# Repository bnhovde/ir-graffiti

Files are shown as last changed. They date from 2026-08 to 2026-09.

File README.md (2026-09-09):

# IR Graffiti — spray can tracker

A handheld spray can emits infrared; a camera watches for it and paints where it
points.

**Status: it works.** A person picks up the can, points it at the TV, holds the
button and paints. All three of the original blockers are closed — manual
exposure, the LED's beam angle, and the Pi's power supply — and the Pi boots
into the wall unattended.

It works on the *interim* optics: a modified C910 behind a strip of VHS tape.
The mono global-shutter camera and the 850 nm bandpass filter are still in
transit, and they are what will make it robust rather than merely working.
Honest summary of where it stands:

| | |
|---|---|
| Can: 850 nm, 120°, one emitter | ✅ tracks reliably at painting distance |
| Power | ✅ 5 V/5 A negotiated, no throttling |
| Tracker | ✅ 30 fps, 4.6× margin over threshold |
| Wall app, calibration, painting | ✅ |
| Controls usable with the can | ✅ colour, mode, size |
| Boots into the wall by itself | ✅ user services, always ends at calibration |
| Rendering | ✅ **58.4 fps while painting** on a Pi 5 at 720p — the rewrite, against 24 for the original |
| Cooling | ✅ Active Cooler fitted: 53 °C, `throttled=0x0`, full 2.4 GHz (was 82 °C and throttling) |
| Latency | ⚠️ dominated by the C910's USB/MJPEG pipeline, ~60–130 ms, which only the CSI camera removes |
| Mono camera + bandpass filter | ⏳ in transit, untested |
| Usable cone angle | ⏳ never measured — `tools/pi/measure.py` is ready |
| Multiple simultaneous users | ❌ unsolved, unscoped |

## Try it

**▶ [bnhovde.github.io/ir-graffiti/test-wall.html](https://bnhovde.github.io/ir-graffiti/test-wall.html)**

Served from GitHub Pages off `main`, so it updates on every push.

- **Camera on the same machine:** camera panel → **IR can** → pick the camera →
  **Diagnostics** → **Calibrate 4 corners**.
- **Tracking on a Pi:** camera panel → **IR (Pi)** → **Connect** (it prefills
  `ws://<host>:8765`) → **Calibrate 4 corners**. The browser never sees pixels in
  this mode, only coordinates, so the diagnostics overlay has nothing to draw —
  use the tracker's own `/preview` instead.

Mouse and touch work without any of the hardware, if you just want to see the
wall itself.

To run it locally instead:

```bash
python3 -m http.server 8731
open http://localhost:8731/test-wall.html
```

Use `localhost`, not `file://` — `getUserMedia` only works in a secure context,
which `localhost` and HTTPS satisfy and a local file does not.

---

## Running it on the Pi

The Pi boots into the wall. Two systemd **user** services do it — user rather
than system because the browser needs the compositor, and `WAYLAND_DISPLAY`
only means anything inside the graphical session. The Pi autologins, so the
session exists at boot and these come up with it. No `linger`, no `sudo`.

```bash
git clone https://github.com/bnhovde/ir-graffiti ~/ir-graffiti
cd ~/ir-graffiti && ./tools/pi/install-pi.sh
systemctl --user restart irtracker irkiosk
```

| | |
|---|---|
| `irtracker` | the tracker: camera, detection, WebSocket on :8765, HTTP on :8000 |
| `irkiosk` | `start-kiosk.sh` — waits for the compositor, sets 720p, launches Chromium, connects it to the tracker, **starts calibration** |
| logs | `~/ir-graffiti/tracker.log`, `~/ir-graffiti/kiosk.log` |

**It always ends at the four corner targets.** The homography lives in the page,
so every restart genuinely needs it redone — and a wall that looks alive but
paints nothing is worse than one visibly asking to be calibrated.

720p is set on every boot because `wlr-randr` does not persist, and because the
resolution is the wall's frame rate: measured ~10 fps at 1440p, ~15 at 1080p and
34+ at 720p. The cost is pure fill rate.

### Why there are two walls

[`wall.html`](wall.html) is the one that boots. [`test-wall.html`](test-wall.html)
is the original and stays as a fallback — `WALL_URL` in `start-kiosk.sh` switches
between them.

The rewrite exists because the original's losses were structural, not tuning.
Measured on the Pi at 720p, while painting:

| | original | rewrite |
|---|---|---|
| painting | 24 fps | **58.4 fps** |
| idle | 60 fps | 60 fps |

Three canvases composited every frame became one that is never cleared; a
full-screen overlay cleared per frame to draw a cursor became a DOM element
moved by a transform; per-stamp gradients became cached bitmaps; and the
backing store is capped at 1×. Nothing animates on its own, so an idle wall
costs nothing and each theme's effects are paid for only while that theme is
selected.

### Operating it at the exhibition

The wall boots by itself and ends at the four corner targets. Everything else
is reachable **with the can alone** — rest it on a control and hold; a ring
fills, then the menu opens; move to highlight, release to pick.

| control | where | what |
|---|---|---|
| sizes · mode · colours | bottom left | five brush sizes, four modes, four colours |
| clear | top right | **hold ~1.8 s** — twice the menu dwell, because it wipes the wall |
| the frog | bottom right | **Calibrate · Reload · Friedolin · Sound** |

**Calibrate** is the one to know. The homography lives in the page, so any
reload needs it redone — and if the camera is nudged, the paint will land in
the wrong place until you recalibrate. It is in the frog menu precisely so
nobody needs a keyboard to fix it.

**Friedolin** places a large frog stencil: paint fills the silhouette and is
cut off outside it. Same item toggles it off.

**Sound** mutes the spray hiss and the choice persists. Worth knowing before
opening rather than after.

Modes are isolated by construction: Space builds its own animated layer on
entry and tears it down on exit, so nothing pays for it while another mode is
selected. Two cans paint at once, sharing a brush — the tracker matches spots
between frames, and when they cross the identities swap, which is invisible
while both use the same colour.

### Driving it with no mouse or keyboard

The exhibition Pi has neither, so [`tools/pi/kiosk.py`](tools/pi/kiosk.py) drives
the page over the Chrome DevTools Protocol:

```bash
python3 tools/pi/kiosk.py --status          # tracker state, calibration, lock
python3 tools/pi/kiosk.py --calibrate       # restart the 4-corner calibration
python3 tools/pi/kiosk.py --latency         # end-to-end latency, while painting
python3 tools/pi/kiosk.py 'app.clearCanvas()'
```

Also useful: `http://graffiti.local:8000/preview` is a live contrast-stretched
camera view for aiming (a correctly exposed IR frame looks black to a human),
and `/debug-pointer.html` shows just the tracked dot with a latency readout — no
canvas, no painting, so it is the floor the wall can be compared against.

---

## The can

Six printed parts, modelled parametrically in [`canv2.scad`](canv2.scad). All
print without supports. About 160 mm tall, 60 mm diameter.

| Part | Key dimensions | Notes |
|---|---|---|
| `body` | ⌀60 × 145 | 2 mm wall, 15 mm shoulder cone, 18 mm neck with a snap bead. Prints upright, open end down. |
| `cap_body` | ⌀36 × 22.6 | Internal shelf carries the button plate so press force goes into the can, not the plate. Nozzle spout ⌀18, standing 4 mm proud, with the LED cast in its face. |
| `cap_top` | ⌀36, 4.1 plug | Snaps on via a split collet. Pry slot at the seam opposite the nozzle. |
| `button_disc` | ⌀31.7 × 2.5 | Holds the switch. Pin holes on a 12.5 × 4.5 grid. |
| `bottom_cap` | ⌀60 × 65.5 | Snap-in base with a slide-in cradle for the battery holder. Two pry slots at 0° and 180°. |
| `nozzle_cap` | ⌀14.9 × 0.8 | The bezel. Presses into the nozzle rebate and clamps the LED into its cast. Prints flat. |

Set `part=` to export one part, or leave it at `"all"` for the layout view.
Exported STLs are in [`stl/`](stl). Everything derives from the parameter block
at the top; the numbers worth knowing are `fit` (0.30, raise it if parts bind),
`hold_w` (36.20, cut for the CM battery holder), and the LED block below.

### How the emitter mounts

The LED **drops into a cast in the front of the nozzle** and a thin bezel presses
on over it, leaving the body and dome outside. Same pattern as `button_disc`
sitting on its shelf under `cap_top`: a part in a recess, closed by a cover.

Three steps in from the nozzle face:

```
0.0 → 0.8    ⌀15.0 rebate      the bezel sits here
0.8 → 2.0    ⌀8.4 + tab slot   the cast: the LED's own silhouette
2.0 → 2.4    ⌀6.6 relief       so the body seats on its rim, not the slug
```

Two ⌀2.5 wire holes run from the cast back into the wiring chamber. **Solder the
leads on, feed them through, drop the LED in, press the bezel on.**

| Parameter | Value | Why |
|---|---|---|
| `pled_cover_t` | 0.8 | Bezel thickness — all that sits beside the dome, so as thin as the printer holds |
| `pled_cover_fit` | 0.10 | Bezel to rebate. Tight on purpose: a press fit, not the sliding `fit` used elsewhere. A drop of glue behind it if you want it permanent |
| `pled_tab_span` | 14.5 | Untrimmed. Sizes the cast and hence the spout |
| `pled_tab_stag` | 1.5 | The tabs are **staggered, not opposite**. Slot is `tab_w + this`, centred, so the part goes in either way up. Read off a drawing — measure yours |
| `pled_body_h` | 2.4 | Tab plane to body top. Sets how far the body protrudes; more just means more sticks out |

The body ends up 1.2 mm proud and the dome tip 3.8 mm clear of the face, with
nothing in front of the dome — the full 120°.

> [!NOTE]
> **An earlier version loaded the LED from inside the cap**, sliding it forward
> down the bore onto a shoulder, with the tabs as retention. It verified fine and
> was almost impossible to build: you were threading a part with leads already
> soldered to it down a channel you could not see into. Front-loading also means
> the LED never enters the wiring chamber, so the chamber — and the whole cap —
> goes back to its original height, 24.6 mm rather than 28.3.

> [!TIP]
> The ⌀15 rebate ceiling is the largest bridge in the part, about 10 mm across
> but only 0.8 mm deep. If it sags enough that the bezel will not seat flush,
> scrape it or raise `pled_cover_fit`.

### Electronics

| Item | Spec | Notes |
|---|---|---|
| IR LED *(incoming)* | 1 × 8 mm star emitter, **850 nm, 120°**, 3 W rated | Body ⌀8.0 (7.2 across the flats), dome ⌀6.0 × 2.6 tall, thermal slug ⌀6.2, tabs 1.5 × 1.05 spanning 14.5, marked IR+ / IR−. Vf 1.4–1.7 V at 500 mA — **single die, so it runs on 3 V**. Some parts sold as "3 W" are three dies in series at 4.5–5 V and will not light at all here; check before wiring. |
| Resistor | **22 Ω**, 0.25 W | One, in series. Gives ~70 mA — 4× the old drive with plenty of margin. 15 Ω takes it to ~110 mA if you want more range. **Do not drive it at the rated 500 mA:** that is 0.75 W with no heatsink, in a plastic cap, and 2×AAA sag badly at that current. At 70 mA the LED dissipates ~0.1 W and heat is a non-issue. |
| Switch | 12 × 12 mm tactile | 4-leg. See wiring warning below. |
| Battery | 2 × AAA, 3.0 V | Printed holder `AAA_holder_di_CM.stl` from [`AAA_holder.3mf`](AAA_holder.3mf), 36.2 × 56.5 × 12 mm, slides into the base cradle. |
| Camera | Logitech C910, or OV9281 *(incoming)* | See below. |
| Host | Raspberry Pi 5 | Runs the tracker and the browser. **Needs the 27 W supply** — see findings. |

**Superseded:** 2 × ⌀3 mm 940 nm ([Fibel](https://www.fibel.no/product/940nm-sender-og-mottaker-ir-leder/)) at 17 mA through 100 Ω each. Kept here only so the old wiring is recognisable. 940 nm is the worst case for a silicon sensor and the ~±20° beam is what the whole rebuild is about.

---

## Wiring

One branch, one LED. Pressing the button lights it, and that *is* the trigger
signal — the tracker treats "LED visible" as pen-down, so the button needs no
telemetry of its own.

```mermaid
graph LR
    BAT["Battery +<br/>2 x AAA, 3.0 V"]
    SW["Tactile switch<br/>12 x 12 mm<br/>diagonal legs"]
    R["22 ohm<br/>0.25 W"]
    D["IR LED<br/>850 nm, 120 deg<br/>~70 mA"]
    GND["Battery -"]

    BAT -->|red| SW
    SW --> R
    R -->|to IR+| D
    D -->|black, from IR−| GND
```

Polarity is printed on the part: **IR+** and **IR−** next to their tabs, so there
is no long-leg/short-leg guessing any more.

> [!TIP]
> **Solder the leads before fitting the LED**, then feed them back through the
> wire holes. The tabs are bonded to the thermal slug and sink heat fast, so use
> a big tip and be quick.

> [!WARNING]
> **Which switch legs.** On a 4-leg tactile switch the two legs **12.5 mm apart,
> straight across the body,** are one terminal. The two close together on the
> same side are *opposite* terminals — bridging those shorts the switch
> permanently on. Wire two diagonally opposite legs and clip the other two;
> diagonals are always one from each terminal, which is why that's the standard
> trick.

---

## The camera

No longer the weak link — moving the tracker onto a Pi fixed the part that
mattered. The C910 on a Pi is a genuinely usable camera.

### Working today: modified C910 on the Pi

| | |
|---|---|
| **Body** | Logitech C910. USB 2.0 UVC, colour sensor, autofocus, ~78° diagonal field. Roughly 70° horizontal in 16:9, so lateral coverage is about 1.4 × distance. |
| **IR-cut filter** | **Removed.** Physically taken out of the lens stack so the sensor can see near-IR at all. This shifts the focal plane — IR focuses differently from visible — so autofocus sits slightly wrong and is locked in software. |
| **IR-pass filter** | **A strip of VHS tape over the front glass.** Improvised and the weakest optical element in the chain. Worth 2–8× to replace with real filter glass. |
| **Exposure / gain** | **Manual, and it works.** `auto_exposure=1`, `exposure_time_absolute=60` (6 ms), `gain=128`, verified by readback. On macOS every one of these returned min 0 / max 0. See the settings finding below — 2 ms / gain 8 was wrong for this optical chain and capped the range. |
| **Format** | **MJPEG, forced.** V4L2 hands back uncompressed YUYV by default and 720p of that exceeds USB 2.0 bandwidth, so the camera silently settles at 10 fps. Asking for MJPEG first gets 30. |
| **Enumeration** | USB VID `0x046d`, PID `0x0821`. `/dev/video0` on the Pi. |

### Incoming: OV9281 + 850 nm bandpass

Mono global shutter, no Bayer filter (~3× the sensitivity of the colour C910),
and a proper filter instead of tape. Together worth roughly 6–24× signal, which
buys **range**, not angle — see the finding on beam width below.

> [!CAUTION]
> **Do not fit the 850 nm bandpass with the old 940 nm LEDs.** A narrow 850 nm
> passband rejects 940 nm by three or four orders of magnitude. You would see
> nothing at all, and it looks exactly like a dead camera. Swap the LED and the
> filter together.

One risk to watch: narrow bandpass filters blue-shift with incidence angle, so
transmission can fall at the edges of a wide field of view. If the screen corners
go dark, that is why — a wider filter or a 780 nm longpass is the fix.

---

## Two camera geometries, one of them dead

The project was originally drafted around bouncing IR off the wall and watching
the reflection from the back of the room. That does not work and cannot be made
to work at this power level. The camera now sits **at the wall, looking back at
the user**, so it sees the LED directly.

| | Bounce off the wall | Direct view |
|---|---|---|
| Camera position | Back of the room | At the wall, facing the user |
| Path | LED → wall → scatter → camera | LED → camera |
| Result | **No reading at all** | **Verified to 3 m** |
| Shortfall | ~1000× too dim | — |

A diffuse wall scatters the LED's output over a hemisphere and the camera then
collects a vanishing fraction of it. Closing that gap would need several watts
per steradian — an illuminator array, not two LEDs on a pair of AAAs. Correctly
abandoned; **do not revisit.**

The cost of the direct path is that the camera only covers about 1.4 × its
distance from you, so a 2 m wall means standing ~1.5 m back, and accuracy
depends on a homography calibrated at roughly that distance.

---

## Findings

Measured, not assumed.

### ✅ Direct-view tracking reaches 3 m

With the VHS filter fitted, the old 3 mm LEDs at 17 mA and no other
optimisation, the camera tracked the LED reliably to about 3 m **when pointed at
the lens**. That last clause is the whole problem — see the beam-angle finding —
but as a range figure it is the baseline everything else is measured against.

### ❌ Bouncing off the wall is ~1000× short

No reading whatsoever off a wall, at any distance, while the direct path was
comfortable. See above.

### ❌ macOS will not expose UVC camera controls — ✅ Linux will

`uvcc` enumerates the C910 correctly on macOS but every control transfer hangs,
and `uvcc ranges` returns min 0 / max 0 for every control: the system's own UVC
driver owns the control interface and will not release it. AVFoundation ignores
exposure and gain too.

**On the Pi the same camera reports `exposure_time_absolute` min 3 max 2047 and
honours it.** This was the project's oldest blocker and the fix was to change
host, not camera. At 2 ms with gain 8 the room reads luma 5 — near-black — which
is exactly the intent: ambient accumulates with exposure time while the LED
saturates almost instantly.

### ✅ Settings, measured rather than assumed

The working configuration for the modified C910 behind VHS tape:

```
exposure  6000 us (6 ms)      gain  128
min_luma  25                  floor 12
```

Exposure sweep, LED at painting distance, gain 128:

| exposure | sig | thr | result |
|---|---|---|---|
| 2 ms | 16.9 | 12.0 | no detection |
| **6 ms** | **55.4** | 12.0 | **LOCKED** — 4.6× margin, threshold still on its floor |
| 10 ms | 78.6 | 17.2 | locked, but margin flat |
| 20 ms | 123.6 | 29.7 | locked, ambient now paying for it |

Past 6 ms the adaptive threshold rises with the signal, so the margin stops
improving and only the room light grows. Short exposure is still what rejects
ambient — 6 ms is short — but **2 ms was dogma, not a measurement**, and it was
carried for most of this project on the strength of the sentence above it.

Two settings were quietly limiting range for weeks:

- **`min_luma` is an ABSOLUTE pixel threshold**, so its meaning moves with gain
  and exposure. It was set to 55 once, to kill false positives, and from then on
  a blob had to exceed 55/255 no matter how the camera was configured. It should
  sit just above sensor noise and let the adaptive threshold and the persistence
  gating filter properly.
- **`--gain` meant different things on the two backends** — an analogue
  multiplier on picamera2, a 0–255 register on a UVC webcam — and shared one
  default of 8.0. Sensible for picamera; very nearly nothing on a webcam. The
  C910 ran at 8/255 for this entire project. Each backend now carries its own
  default.

Symptom to recognise: detection that works close up and **vanishes as a cliff**
rather than fading. That is an absolute gate, not a weak emitter. Hours went into
checking the LED, the batteries, the solder joints and the camera aim, all of
which were fine, because a working measurement of `peak 66` against a gate of
`55` was read as "working" rather than "20% from failing".

### ⚠️ Current blocker: the LED's beam, not the signal

The old 3 mm LEDs held lock only within roughly ±20°, so the can had to be aimed
at the camera rather than painted with.

The decisive measurement: **the same ±20° cone appeared on a Mac at ~16 ms auto
exposure and on a Pi at 2 ms manual.** Two sensitivity regimes an order of
magnitude apart, identical usable angle. A signal problem cannot survive that, so
the limit is the beam.

The arithmetic agrees. Falloff is roughly cos²²θ, so sensitivity barely moves the
angle — 6–24× more signal widens the usable half-angle from about 20° to 23–30°.
The same 6–24× spent on range buys 2.4–5×, because that goes as the square root.

**The fix is a wider emitter, not a brighter one.** A 120° part changes the
exponent rather than the multiplier. At 45° off-axis the old LED is at ~0.0005 of
peak and a 120° one is at ~0.7.

### ✅ The C910's first open returns a dead stream

Worth knowing because it wastes an evening. The camera enumerates, streams at a
valid 30 fps, and every pixel of every frame is the same value. It looks exactly
like a blocked lens. The kernel log shows the real cause — the first probe fails
with `-5` and the device re-enumerates — and Photo Booth shows the same thing:
you have to select the camera, select another, and select it back.

`tracker.py` now validates at startup while still on auto exposure, where a live
sensor always shows read noise, and reopens on a single-valued frame. Checking
after the switch to 2 ms would not work: a dark room at 2 ms is legitimately
almost flat.

### ❌ A 15 W supply will not run a Pi 5 with this camera

Three hard crashes, then a fourth. The firmware says why:

```
max_current              = 3000     5 V x 3 A = 15 W
usb_max_current_enable   = 0        USB peripherals capped at 600 mA total
usbpd_power_data_objects = 0 0 0    no PD profile offered at all
```

A MacBook charger does not advertise a 5 V/5 A profile, so the Pi falls back to
5 V/3 A and clamps **all** USB peripherals to 600 mA combined. The C910 alone can
draw 500 mA of that. Under load the board browns out and resets.

Confirmed by watching `vcgencmd get_throttled` flip to `0x50000` (under-voltage
and throttling both latched) within 20 seconds of the camera streaming, **with no
browser running at all**. Dropping the display to 1080p helped and was not
enough.

Use the official 27 W supply. Do **not** set `usb_max_current_enable=1`, the
common forum advice — it lifts the safety cap without adding a single watt, and
converts a clean refusal into an unpredictable brownout. A powered hub for the
camera is a legitimate workaround; it takes 500 mA off the Pi's budget entirely.

---

## Open questions

**~~Projector lamp~~ — settled.** The display is an **LED TV**, which emits no
meaningful near-IR, so the projector-lamp question is moot and a modest filter
suffices. Recorded because it drove several earlier decisions.

**Multi-user — unsolved, and in scope.** Identical IR LEDs are indistinguishable
and the tracker finds exactly one blob. Two cans in frame gives two spots with no
way to tell which is which. Telling them apart means blink-coding an ID into each
can, which means a microcontroller per can. None of the incoming hardware
addresses this. It is genuine new engineering and remains unscoped.

**Calibration in anger.** The 4-corner homography has never been completed on the
Pi — the board browned out first. Nothing paints without it: `processFrame()`
returns null with no homography, by design.

**Room lighting** — less of a risk than it sounds. Behind a proper filter, LED
and fluorescent lighting are nearly invisible; they emit almost no near-IR.
Brightness is not the variable, spectrum is. Halogen, incandescent and daylight
are the ones that hurt.

---

## Next step

Assemble the new emitter and **measure the usable cone before changing anything
else**. Hold the can at a fixed distance and rotate it until lock drops. If that
is not at least ±45°, the beam-angle reasoning above is wrong and the right move
is to re-measure, not to pile on more changes.

Then, in order: 27 W supply, new camera and filter together, 4-corner
calibration, and only then multi-user.

> [!NOTE]
> **A correction worth keeping.** An earlier version of this file recommended
> TSAL6100/6200-class emitters, chosen for intensity. Those are narrow-beam parts
> — roughly ±10° and ±17° — and that advice was backwards. Now that beam angle is
> known to be the binding constraint and there is 30× of sensitivity in reserve
> (the tracker locks at gain 8 of 255 and 2 ms of a possible 205), the selection
> criterion is the **widest** half-angle available at 850 nm, not the brightest.

**Rear projection is also dead** as a suggestion: the display is an LED TV.

None of the can hardware is wasted by any of this. Enclosure, button, battery
holder and switch wiring all carry over; only the LED and its resistor change.

Sourcing from Norway: Digi-Key, Mouser and Elfa Distrelec all ship and are
VOEC-registered (VAT at checkout, no customs handling fee). Arducam direct, The
Pi Hut, or BerryBase for the camera. AliExpress is fine for the filter.

---

## Repository layout

| Path | What |
|---|---|
| [`canv2.scad`](canv2.scad) | Parametric model, all five parts |
| [`stl/`](stl) | Exported STLs |
| [`AAA_holder.3mf`](AAA_holder.3mf) | Third-party battery holder. Use the `AAA_holder_di_CM.stl` variant — the cradle is cut for its 36.2 mm width |
| [`test-wall.html`](test-wall.html) | The wall app — [live](https://bnhovde.github.io/ir-graffiti/test-wall.html). Has an **IR can** camera mode: pure-JS blob tracking, rolling background, 4-corner homography calibration, and a diagnostics overlay showing the brightest pixel with no thresholding applied. `app.irTracker` is exposed on the console for tuning |
| [`tools/pi/tracker.py`](tools/pi/tracker.py) | **The Pi tracker.** Captures, finds the blob, broadcasts normalised coordinates over a WebSocket on :8765, and optionally serves the repo over HTTP. `--source picamera\|webcam\|synthetic`. Also serves a live contrast-stretched camera preview at `/preview` for aiming — necessary because a correctly exposed IR frame looks black to a human |
| [`tools/pi/kiosk.py`](tools/pi/kiosk.py) | Drives the wall app in a kiosk browser over the Chrome DevTools Protocol, for a Pi with no mouse. `--connect`, `--calibrate`, `--status`. Also takes a screen wake lock |
| [`tools/irtest.py`](tools/irtest.py) | Standalone Python tuner for the same pipeline, with a live HUD. Needs `opencv-python` |
| [`tools/ircam-setup.sh`](tools/ircam-setup.sh) | Attempts manual camera control via `uvcc`. **Known not to work on macOS**, and superseded on Linux by `tracker.py`, which sets the same controls through `v4l2-ctl` and reads them back |
| [`canv1.scad`](canv1.scad) | Superseded first draft, kept for reference |

### Reading the diagnostics overlay

In order — each step is only worth doing if the previous one passed.

0. **In Pi mode, none of this applies** — the browser receives coordinates, not
   pixels. Use the tracker's `/preview` page and its `--stats` line instead.
1. **`camera`** — if that's not the modified camera, nothing else matters.
2. **Red cross** — the brightest pixel in the frame, no thresholds at all. Press
   the button. If red doesn't jump to the LED, the problem is upstream of all
   this software.
3. **`maxLuma` / `maxSig`** with the LED on vs off. That difference is the entire
   signal budget.
4. Only if red lands correctly but no green circle appears is the sensitivity
   slider (`k`) the thing to touch.

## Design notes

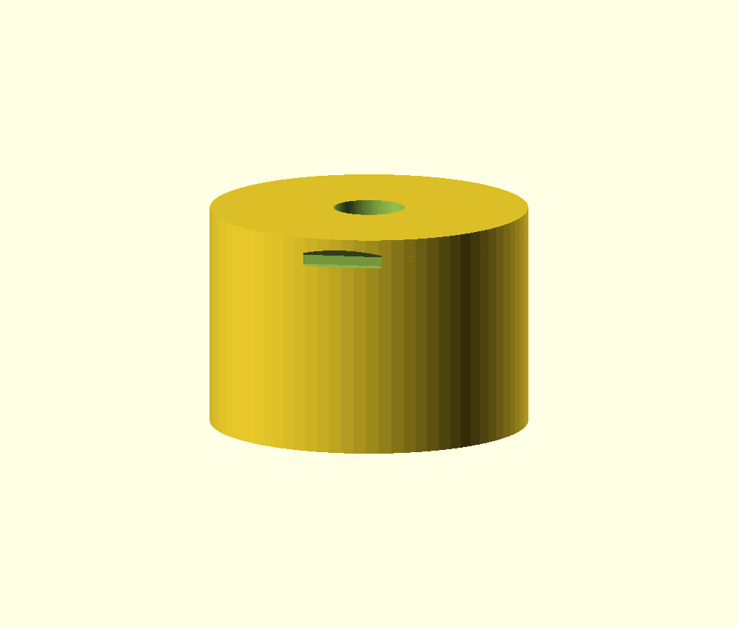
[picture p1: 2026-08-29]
preview_pry.png

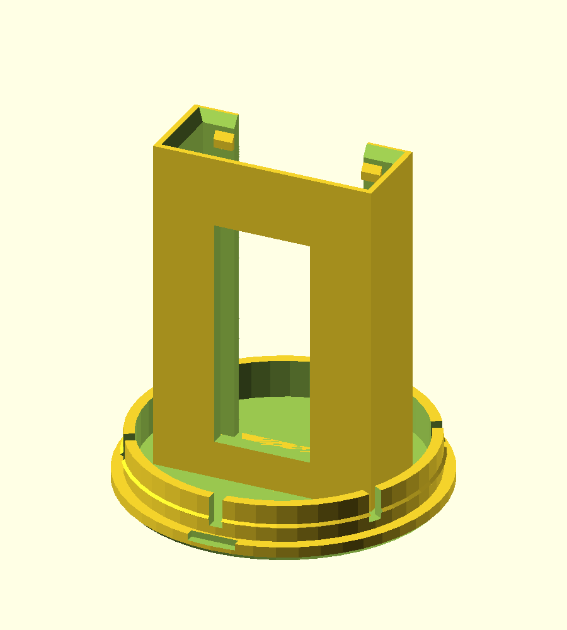
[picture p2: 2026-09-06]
preview_cradle.png

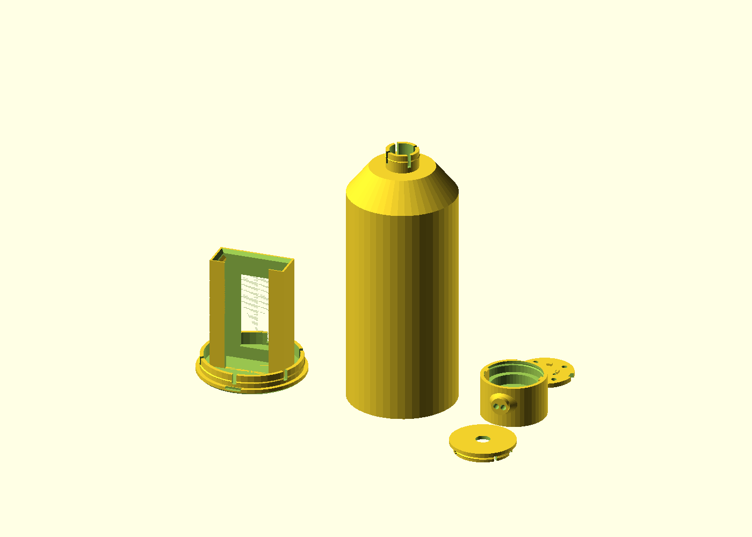
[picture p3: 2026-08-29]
preview.png

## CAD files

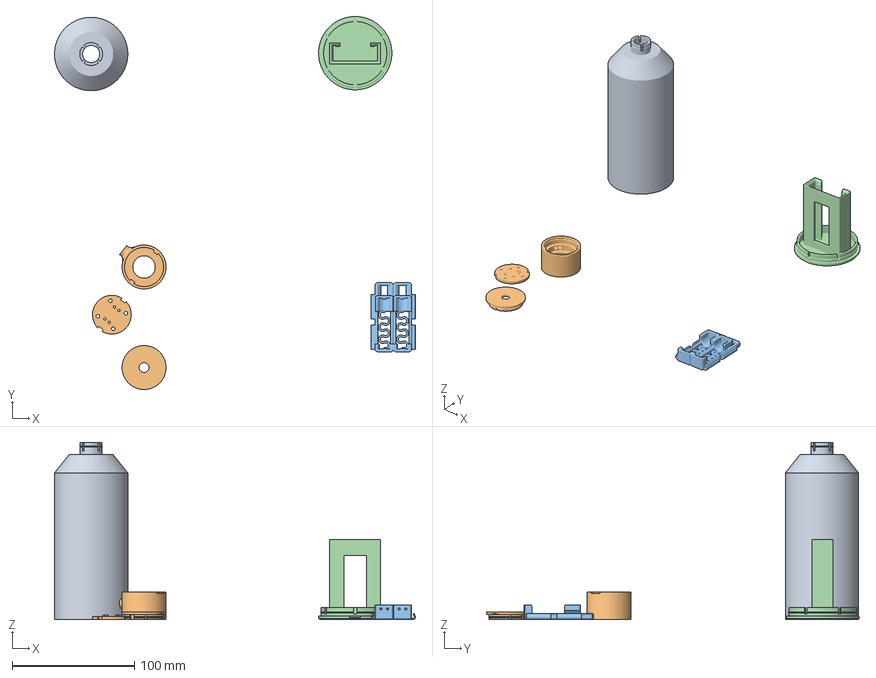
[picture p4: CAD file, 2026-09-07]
Full project September 6.3mf
295.3 x 305.1 x 145.0 mm
body.stl
button_disc
AAA_holder_di_CM.stl
bottom_cap.stl

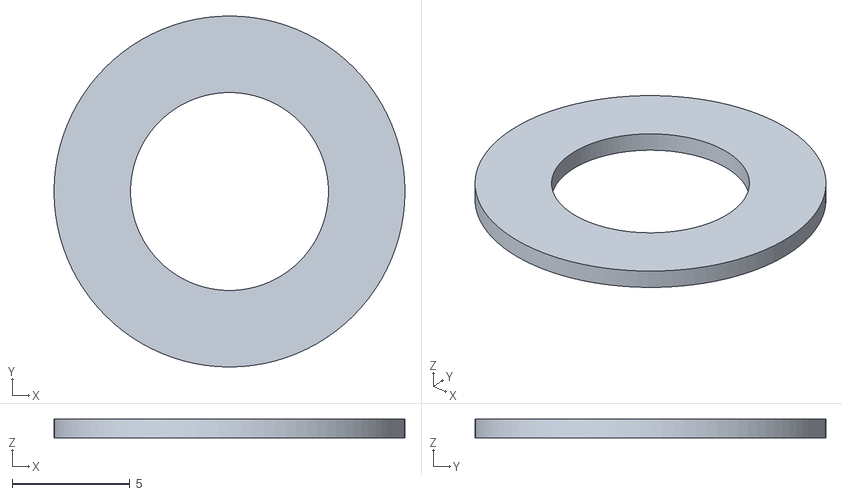
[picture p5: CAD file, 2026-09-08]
stl/nozzle_cap.stl
14.9 x 14.9 x 0.8

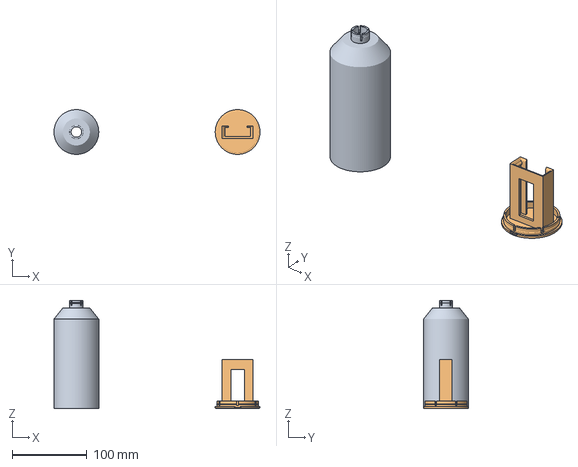
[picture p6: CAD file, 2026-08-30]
project.3mf
276.0 x 60.0 x 145.0 mm
body.stl
bottom_cap.stl

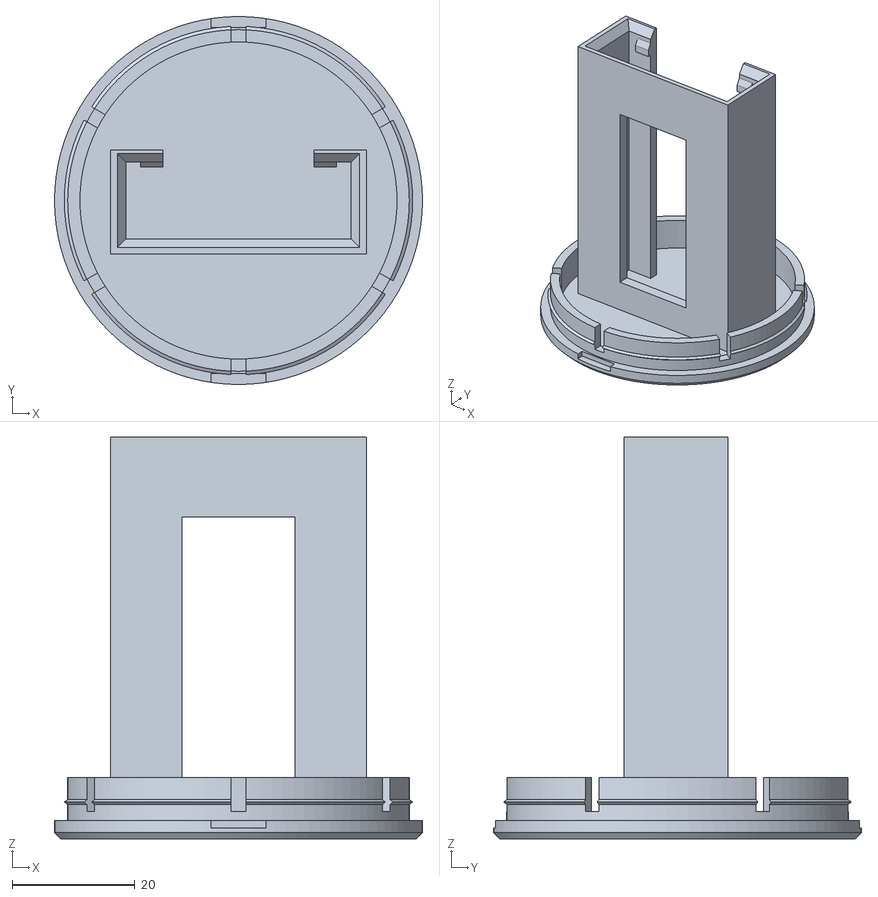
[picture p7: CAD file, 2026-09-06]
stl/bottom_cap.stl
60.0 x 60.0 x 65.5

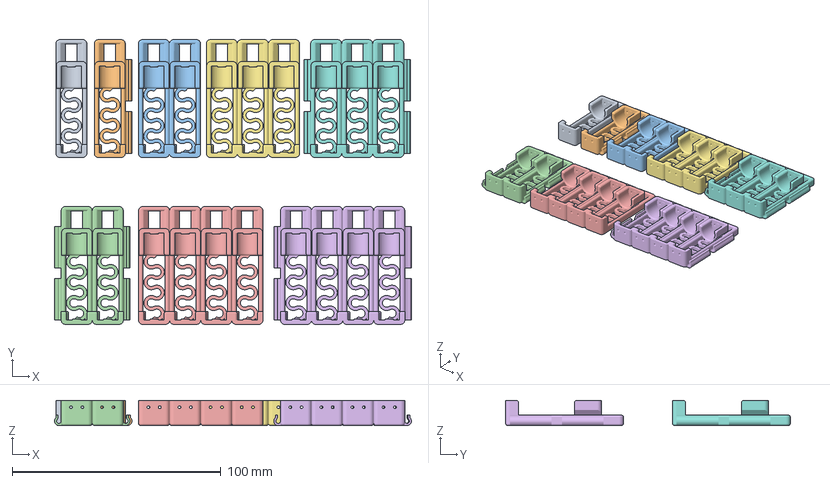
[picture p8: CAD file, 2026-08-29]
AAA_holder.3mf
171.1 x 136.5 x 12.0 mm
AAA_holder.stl
AAA_holder_CM.stl
AAA_holder_di.stl
AAA_holder_di_CM.stl
AAA_holder_tetra.stl
AAA_holder_tetra_CM.stl
AAA_holder_tri.stl
AAA_holder_tri_CM.stl

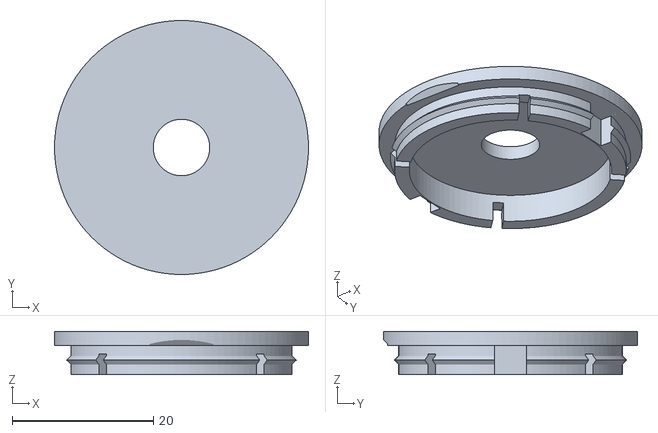
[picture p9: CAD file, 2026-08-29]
stl/cap_top.stl
36.0 x 36.0 x 6.10

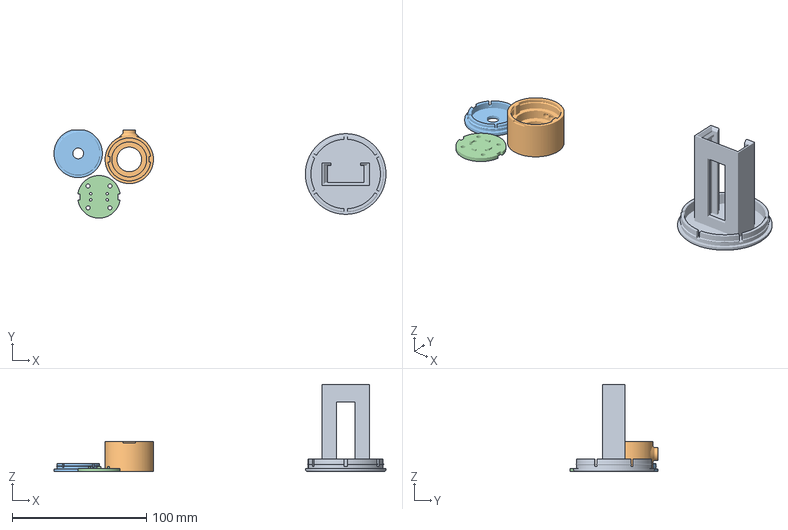
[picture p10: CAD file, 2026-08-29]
stl/cap_body.3mf
247.0 x 65.7 x 65.0 mm
bottom_cap.stl
cap_body.stl
cap_top.stl
button_disc.stl

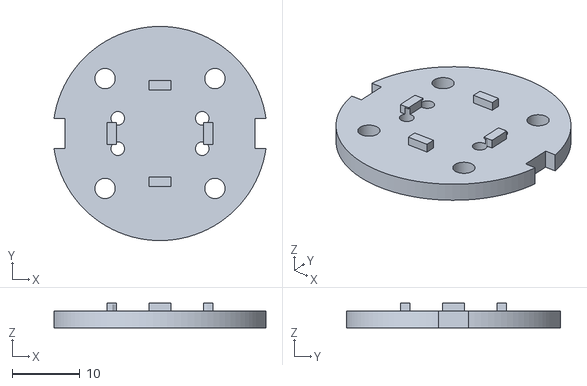
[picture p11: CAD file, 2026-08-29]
stl/button_disc.stl
31.4 x 31.7 x 3.70

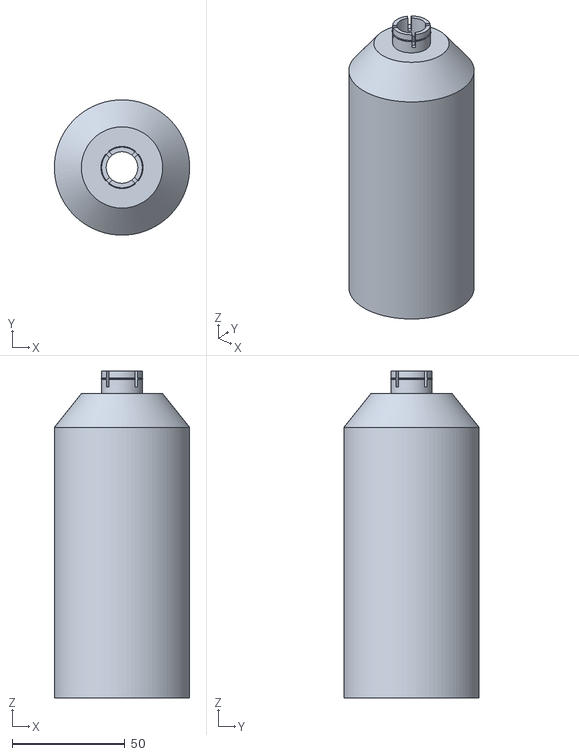
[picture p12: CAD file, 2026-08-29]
stl/body.stl
60.0 x 60.0 x 145.0

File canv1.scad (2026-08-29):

/*
  Digital Graffiti Spray Can Enclosure
  Modular Design with Through-Cut Alignment Grooves & External Battery Slot
*/

can_diameter = 60;
can_height = 120;
cap_height = 25;
wall_thickness = 2;

cap_outer_d = 28;
cap_inner_d = cap_outer_d - (wall_thickness * 2); 

led_hole_diam = 3.2; 

// Tactile Switch Mount Dimensions
switch_width = 12.4;     
switch_base_h = 3.5;     
switch_actuator_d = 8.0; 
pin_pitch_x = 12.5; 
pin_pitch_y = 4.5;  
pin_hole_diam = 2.0;

// External Battery Holder Dimensions (Adjust these to match your AAA_holder.3mf)
holder_w = 26.0;  // Width of external holder
holder_d = 13.0;  // Depth/thickness of external holder
holder_h = 48.0;  // Height/length of external holder
holder_tol = 0.3; // Clearance for sliding fit

$fn = 100;

// --- 1. Main Body Module ---
module main_body() {
    difference() {
        union() {
            cylinder(h=can_height, d=can_diameter);
            translate([0, 0, can_height])
                cylinder(h=15, d1=can_diameter, d2=cap_outer_d);
            translate([0, 0, can_height + 15])
                cylinder(h=8, d=cap_inner_d - 0.4); 
        }

        translate([0, 0, -wall_thickness])
        union() {
            cylinder(h=can_height, d=can_diameter - (wall_thickness*2));
            translate([0, 0, can_height])
                cylinder(h=15, d1=can_diameter - (wall_thickness*2), d2=cap_inner_d - 0.4 - (wall_thickness*2));
            translate([0, 0, can_height + 15])
                cylinder(h=12, d=cap_inner_d - 0.4 - (wall_thickness*2));
        }
    }
}

// --- 2. Detachable Top Cap Module ---
module top_cap() {
    union() {
        difference() {
            cylinder(h=cap_height, d=cap_outer_d);

            translate([0, 0, -0.1])
                cylinder(h=cap_height - wall_thickness - switch_base_h + 0.1, d=cap_inner_d);

            translate([0, 0, cap_height - 5])
                cylinder(h=10, d=switch_actuator_d);

            translate([-(switch_width/2), -(switch_width/2), cap_height - wall_thickness - switch_base_h])
                cube([switch_width, switch_width, switch_base_h + 0.1]);

            translate([-10, -6, cap_height/2])
                rotate([0, 90, 0])
                cylinder(h=30, d=led_hole_diam);

            translate([-10, 6, cap_height/2])
                rotate([0, 90, 0])
                cylinder(h=30, d=led_hole_diam);
        }
        
        // Alignment Rails
        translate([(cap_inner_d/2) - 1, -1, 0])
            cube([1, 2, cap_height - wall_thickness - switch_base_h]);
            
        translate([-(cap_inner_d/2), -1, 0])
            cube([1, 2, cap_height - wall_thickness - switch_base_h]);
    }
}

// --- 3. Bottom Lid & External Battery Holder Clip ---
module bottom_cap() {
    union() {
        // Base plate
        cylinder(h=wall_thickness, d=can_diameter);
        
        // Insert lip
        translate([0, 0, wall_thickness])
            cylinder(h=5, d=can_diameter - (wall_thickness*2) - 0.4);
            
        // Slot/Bracket for external battery holder
        translate([0, 0, wall_thickness])
        union() {
            difference() {
                // Outer retaining sleeve
                translate([0, 0, holder_h/2])
                    cube([holder_w + 4, holder_d + 4, holder_h], center=true);

                // Inner slot cavity
                translate([0, 0, holder_h/2 + 1]) 
                    cube([holder_w + (holder_tol*2), holder_d + (holder_tol*2), holder_h + 2], center=true);

                // Front cutout to allow flex (creates the snap "clip" action)
                translate([0, holder_d/2, holder_h/2 + 2])
                    cube([holder_w - 8, 4, holder_h + 2], center=true);
                    
                // Wire routing holes at the base of the slot
                translate([-6, 0, -1]) cylinder(h=5, d=3.5);
                translate([6, 0, -1]) cylinder(h=5, d=3.5);
            }
            
            // Snap-fit retention bumps (detents) inside the top of the sleeve
            translate([(holder_w/2) + holder_tol - 0.2, 0, holder_h - 4])
                sphere(d=1.5);
            translate([-((holder_w/2) + holder_tol - 0.2), 0, holder_h - 4])
                sphere(d=1.5);
        }
    }
}

// --- 4. Button Locking Disc Module ---
module button_locking_disc() {
    difference() {
        cylinder(h=2, d=cap_inner_d - 0.2);

        // 4 Pin Holes
        translate([pin_pitch_x/2, pin_pitch_y/2, -1]) cylinder(h=4, d=pin_hole_diam);
        translate([pin_pitch_x/2, -pin_pitch_y/2, -1]) cylinder(h=4, d=pin_hole_diam);
        translate([-pin_pitch_x/2, pin_pitch_y/2, -1]) cylinder(h=4, d=pin_hole_diam);
        translate([-pin_pitch_x/2, -pin_pitch_y/2, -1]) cylinder(h=4, d=pin_hole_diam);
            
        // Through-Cut Alignment Grooves
        translate([(cap_inner_d/2) - 0.5, 0, 1])
            cube([3, 2.4, 4], center=true);
            
        translate([-(cap_inner_d/2) + 0.5, 0, 1])
            cube([3, 2.4, 4], center=true);
    }
}

// --- 5. Render Layout ---
main_body();

translate([can_diameter + 15, 0, 0])
    bottom_cap();

translate([-can_diameter/2 - 15, 0, 0])
    top_cap();

translate([-can_diameter/2 - 15, cap_outer_d + 15, 0])
    button_locking_disc();

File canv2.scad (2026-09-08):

/* ============================================================================
   Digital Graffiti Spray Can Enclosure  --  v2
   ----------------------------------------------------------------------------
   Changes vs v1:

     1) CAP is now three parts. The button plate can no longer be pushed down:
        it drops onto a solid internal shelf in cap_body and is clamped there
        by the plug on cap_top, which snaps into cap_body. Finger force goes
        disc -> shelf -> can, not into the disc's edges.

     2) BATTERY BOX is gone. The bottom cap now carries a slide-in cradle for
        the printed AAA_holder_di_CM.stl (dual AAA with cable management,
        36.2 x 56.5 x 12 mm) out of AAA_holder.3mf. Pull the bottom cap off and
        the loaded holder comes with it, open face outward, batteries fully
        accessible.

   PRINT ORIENTATION (no supports anywhere)
     body        : as modelled, upright, open end down.
     cap_body    : as modelled, rim up. The nozzle's 45 deg collar keeps it
                   support-free; only ~3 mm under the spout tip bridges.
     cap_top     : UPSIDE DOWN - roof flat on the bed, plug pointing up.
     button_disc : flat.
     bottom_cap  : as modelled, plate on the bed.

   LED AIM
     The LEDs fire radially, out a nozzle boss on the side of the cap - the way
     a real spray can sprays. Hold the can upright with your finger on the
     button and the nozzle toward the wall.

     NOTE, 30 Aug 2026: the original plan was for the IR to bounce off the wall
     and be seen by a camera at the back of the room. That was measured and is
     dead - roughly 1000x too dim. The camera now sits AT the wall looking back
     at the user, so the nozzle points straight at it and the camera sees the
     LEDs directly, so the radial nozzle is still correct; only the camera
     moved.

     NOTE, 8 Sep 2026: the pair of 3 mm 940 nm indicators is gone, replaced by
     a single 8 mm 3 W 850 nm emitter with a 120 degree beam. Measured on both
     a Mac at 16 ms auto exposure and a Pi at 2 ms manual, the old LEDs held
     lock only within about +/-20 degrees - the same cone in two sensitivity
     regimes an order of magnitude apart, which says the limit was the beam,
     not the signal. The "front" and "side" LED modes went with them.

   ASSEMBLY
     To open either end: flat screwdriver into the slot at the seam, twist. Up
     top there is one, opposite the nozzle; at the bottom there are two,
     opposite each other, so you can walk the cap off level. In both cases the
     blade bears on the fixed part one way and the removable part the other.

     Push each LED down its nozzle channel from inside the wiring chamber until
     the dome is flush with the spout tip; leads run back into the chamber.
     Solder the switch to button_disc, drop the disc into cap_body onto the
     shelf (two flats key it), and bring the LED leads up through the disc's
     wire holes. Feed the battery wires up through the neck. Push cap_top on
     until it clicks. Load the AAA holder outside the can, slide it down into
     the cradle until it clicks past the two tabs, push the bottom cap home.
   ========================================================================== */

$fn = 96;

/* [What to render] */
// all | assembly | body | cap_body | cap_top | button_disc | bottom_cap
part = "all";

/* [Fit] */
fit    = 0.30;   // general sliding clearance - raise if parts bind
snap_r = 0.45;   // radial engagement of the cap_top snap bead

/* [Can] */
can_d   = 60;
can_h   = 120;
wall    = 2;
taper_h = 15;    // height of the shoulder cone

/* [Neck - where the cap grips] */
neck_d    = 18;
neck_h    = 10;
neck_bore = neck_d - 2*wall;   // 14 - wires pass through here
neck_bead = 0.35;              // radial snap bead (set 0 for plain friction)

/* [Cap] */
cap_od    = 36;
cap_wall  = 2;
roof_gap  = 0.6; // clearance over the switch body - keep > 0 or the roof holds
                 // the button permanently pressed. Also sets the plug depth.
roof_th   = 2;
disc_th   = 2.5;

/* [Tactile switch - 12x12 through hole] */
sw_body   = 12.4;  // body footprint - confirmed, fits canv1's square pocket
sw_body_h = 3.5;   // body height above the disc            (datasheet)
sw_stem_h = 1.5;   // plunger height above the body. Reference only - nothing is
                   // derived from it. roof_gap guarantees the roof never touches
                   // the switch, and the plunger is reached through sw_hole_d
                   // whether it ends up proud of the roof or a little recessed.
sw_hole_d = 8.0;   // finger hole in the roof, same as canv1
sw_pin_x  = 12.5;  // confirmed, legs fit canv1's disc
sw_pin_y  = 4.5;   // (datasheet)
sw_pin_d  = 2.0;

/* [IR LED - one 8 mm 3 W emitter, 850 nm, 120 degree]
   Radial, out a nozzle boss on the side of the cap, the way a real spray can
   sprays - which is also straight at the camera, since the camera sits at the
   screen looking back at the user.

   The emitter drops into a cast in the FRONT of the nozzle - a recess cut to
   its own silhouette, body circle plus tab slot - and a thin bezel goes on over
   it, leaving only the body and the dome outside. Wires reach the tabs through
   two holes running back into the wiring chamber.

   That replaces an earlier scheme where the LED went in from inside the cap and
   slid forward down the bore. It was, in Bard's words, almost impossible to
   slot in: you were threading a part with leads already soldered to it down a
   channel you could not see into. Loading from the front is the same idea as
   button_disc on its shelf under cap_top, and the LED no longer passes through
   the wiring chamber at all - which is why the chamber, and the whole cap,
   goes back to its original height.

   From the drawing: body 8.0 round (7.2 across the flats), dome / die disc 6.0
   standing 2.6 proud of the body top, thermal slug 6.2 underneath, tabs 1.5
   wide x 1.05 thick spanning 14.5 tip to tip, marked IR+ / IR-. */
nozzle_out    = 4.0;    // how far the nozzle spout stands proud of the cap
pled_body_d   = 8.0;
pled_dome_d   = 6.0;
pled_dome_h   = 2.6;
pled_slug_d   = 6.2;    // thermal slug on the underside - gets its own relief
                        // so the body seats on its rim, not on the slug
pled_body_h   = 2.4;    // tab plane to the top of the body, dome excluded.
                        // Sets how far the body ends up standing out; if yours
                        // measures more, more of it protrudes and nothing else
                        // changes.
pled_tab_w    = 1.5;    // tab width
pled_tab_t    = 1.05;   // tab thickness - the bezel clamps this
pled_tab_span = 14.5;   // tip to tip, untrimmed. Sizes the cast and the spout.
pled_tab_stag = 1.5;    // THE TABS ARE STAGGERED, not opposite each other: one
                        // leaves high, the other low. The slot is tab width +
                        // this, centred, so the part goes in either way up.
                        // Read off a drawing - measure yours and tighten it.
pled_cover_t  = 0.8;    // the bezel: as thin as the printer will hold, since
                        // it is all that sits beside the dome
pled_cover_fit= 0.10;   // bezel to rebate. Tight on purpose - this is a press
                        // fit, not the sliding `fit` used elsewhere. A drop of
                        // glue behind it if you want it permanent.
pled_wire_d   = 2.5;    // wire pass-throughs, cast to chamber

/* [Pry slots - for getting the caps back off] */
pry_w     = 9.0;         // tangential width, both ends
pry_h     = 1.2;         // pocket height, both ends
pry_d     = 1.5;         // top: radial depth (cap wall there is 2.0, 0.5 left)
pry_a     = 180;         // top: which way it faces - 180 = opposite the nozzle
pry_d_bot = 1.8;         // bottom: depth. Must stay under can_d/2 - bplug_od/2
                         // or it undercuts the root of the plug ring.
pry_a_bot = [0, 180];    // bottom: two, so you can walk the cap off evenly

/* [Battery holder pocket - AAA_holder_di_CM.stl out of AAA_holder.3mf]
   Variants in that 3mf, W x L x T:
     AAA_holder_di.stl      29.80 x 56.5 x 12   (no cable management)
     AAA_holder_di_CM.stl   36.20 x 56.5 x 12   <- this one
   On the CM part the extra width is cable-management wings on the back half of
   the thickness only; the battery face is still 29.8 wide. The pocket is cut to
   the full 36.2 so the wings are what the side rails grip, and `lip` is set deep
   enough that the front lips still catch the narrower battery face. */
hold_w   = 36.20;
hold_t   = 12.0;
hold_l   = 56.5;
hold_fit = 0.50;

/* [Bottom cap] */
base_th = 3.0;   // 1.2 of this is the pry pocket, so keep it >= 2.8
base_od = can_d; // set this 2 mm over can_d for a proud foot ring you can get a
                 // blade under anywhere, instead of / as well as the pry slots
bplug_h = 7;
bsnap_r = 0.40;
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

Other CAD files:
stl/cap_body.stl

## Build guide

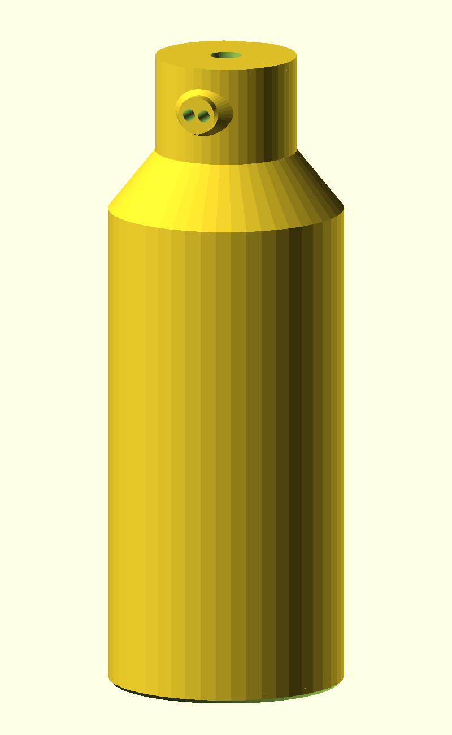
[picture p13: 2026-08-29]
preview_assembly.png

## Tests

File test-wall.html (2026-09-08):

Stencil active — paint only fills the letters Exit stencil

Stencil

Place stencil

Paint over the outline — color only sticks inside the letters.

OR

Use the Friedolin Clear stencil

Camera tracking

Hand Spray can IR can IR (Pi)

Enable camera tracking

tap to allow the webcam

Hold the can inside the box, then tap Calibrate

Calibrate

Point the IR marker at the wall's top-left corner, then tap Capture

Capture corner 1 of 4

Hand tracking live

1 finger draw · fist lift · pinch next color · swipe → clear

Move the can to paint · pull it out of frame to lift the pen

Hold the button to paint · release to lift the pen

Hold the button to paint · tracking runs on the Pi

Connect Calibrate 4 corners

—

Calibrate 4 corners

Sensitivity 10

—

Diagnostics

Turn off camera

How to paint

Drag to paint · pick a color below · the slider sets brush size · switch styles up top · the stencil icon lets you type a word and fill it in

⌘Z undo ⌫ clear S save

Move the can to choose · release to pick

Paint blobs

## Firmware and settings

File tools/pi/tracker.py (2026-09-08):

#!/usr/bin/env python3
"""
IR spot tracker for the Raspberry Pi + OV9281.

Runs headless on the Pi behind the TV. Reads the mono global-shutter camera at a
fixed short exposure, finds the can's IR LED, and broadcasts its position over a
WebSocket. The browser applies the homography and paints - keeping calibration in
the UI, where the corner targets can actually be shown on the TV.

Coordinates sent are normalised IMAGE coordinates (0..1), not screen coordinates.
The Pi stays a dumb blob detector; test-wall.html already has solveHomography.

    # on the Pi
    sudo apt install -y python3-picamera2
    pip3 install websockets numpy
    ./tracker.py --stats

    # anywhere, no camera needed - exercises the same pipeline
    ./tracker.py --source synthetic --stats

Why a fixed short exposure matters more than anything else here: ambient light
accumulates in proportion to exposure time, while a bright LED saturates almost
immediately. At 2 ms a lit room nearly vanishes and the LED still reads 255. This
is the control macOS never let us have, and it does more than any filter.
"""

import argparse
import asyncio
import json
import sys
import threading
import time

import numpy as np

WS_PORT = 8765
HTTP_PORT = 8000


# --------------------------------------------------------------------- detect
class IRTracker:
    """Same pipeline as tools/irtest.py and the browser tracker.

    Rolling background, adaptive threshold, windowed centroid, persistence gate.
    The two non-obvious parts are commented where they appear - both were bugs
    found the hard way.
    """

    def __init__(self, k=10.0, floor=20, min_luma=55, bg_rate=0.02,
                 max_area_frac=0.01, min_area=24, lock_need=3,
                 lock_dist_frac=0.05, max_blobs=2):
        self.k = k
        self.floor = floor
        self.min_luma = min_luma
        self.bg_rate = bg_rate
        self.max_area_frac = max_area_frac
        self.min_area = min_area
        self.max_blobs = max_blobs
        self.lock_need = lock_need
        self.lock_dist_frac = lock_dist_frac
        self.bg = None
        self._tracks = []
        self._next_id = 0
        self.stats = {}
        self._buf = None          # preallocated scratch; see detect()

    def reset(self):
        self.bg = None
        self._tracks = []

    def detect(self, gray):
        """gray: 2-D uint8. Returns a dict or None.

        Written to allocate nothing per frame and to avoid boolean fancy
        indexing, which on a million pixels costs more than everything else in
        here put together. All the heavy numpy calls write into preallocated
        buffers via out=.
        """
        h, w = gray.shape
        n = h * w

        if self._buf is None or self._buf[0].shape != gray.shape:
            self._buf = tuple(np.empty((h, w), np.float32) for _ in range(3))
            self.bg = None
        f, sig, tmp = self._buf

        np.copyto(f, gray)        # uint8 -> float32 in place

        if self.bg is None:
            self.bg = f.copy()
            return []

        np.subtract(f, self.bg, out=sig)
        np.maximum(sig, 0, out=sig)

        mean = float(sig.mean())
        sd = float(sig.std())
        thr = max(self.floor, mean + self.k * sd)

        peak_idx = int(np.argmax(sig))
        peak = float(sig.flat[peak_idx])
        py, px = divmod(peak_idx, w)
        luma = int(gray.flat[peak_idx])

        self.stats = {"max_luma": int(gray.max()), "max_sig": round(peak, 1),
                      "mean": round(mean, 2), "sd": round(sd, 2),
                      "thr": round(thr, 1), "w": w, "h": h}

        # Update the background ONLY where the frame is not currently lit.
        # Otherwise holding the button still burns the LED into the reference
        # and the spot fades after a second or two - you lose the stroke exactly
        # when you stop moving.
        if self.bg_rate:
            np.subtract(f, self.bg, out=tmp)
            tmp *= self.bg_rate
            tmp *= (sig < thr)    # mask as 0/1 multiply, not fancy indexing
            self.bg += tmp

        # ---- find up to max_blobs spots, brightest first -------------------
        # Two people, two cans. Each spot is taken, then blanked out of the
        # signal so the next pass finds the next one rather than the same peak
        # again. Everything a single blob had to satisfy - threshold, min_luma,
        # min_area, max_area - each of these still does.
        r = max(12, w // 14)
        found = []
        for _ in range(self.max_blobs):
            peak_idx = int(np.argmax(sig))
            peak = float(sig.flat[peak_idx])
            if peak < thr:
                break
            py, px = divmod(peak_idx, w)
            luma = int(gray.flat[peak_idx])

            y0, y1 = max(0, py - r), min(h, py + r)
            x0, x1 = max(0, px - r), min(w, px + r)
            win = sig[y0:y1, x0:x1]
            mask = win >= thr
            area = int(mask.sum())
            ok = (luma >= self.min_luma and self.min_area <= area <= self.max_area_frac * n)
            if ok:
                wsum = float(win[mask].sum())
                ys, xs = np.nonzero(mask)
                found.append({
                    "cx": x0 + float((xs * win[ys, xs]).sum()) / wsum,
                    "cy": y0 + float((ys * win[ys, xs]).sum()) / wsum,
                    "area": area, "peak": round(peak), "luma": luma})
            # Blank this peak's window either way: if it failed the gates it is
            # noise or a reflection, and leaving it in would make the next pass
            # pick the very same pixel forever.
            win[mask] = 0.0
            if not ok and peak >= thr:
                sig[max(0, py - 2):py + 3, max(0, px - 2):px + 3] = 0.0

        # ---- match them to last frame's tracks -----------------------------
        # Greedy nearest neighbour. With two blobs that is all it needs to be,
        # and identities only have to survive between frames, not across the
        # whole stroke. When two cans CROSS, the ids swap - invisible while both
        # paint with the same brush, which is exactly why that is the feature
        # worth shipping first.
        limit = self.lock_dist_frac * w
        unused = list(range(len(found)))
        alive = []
        for tr in self._tracks:
            best, bestd = None, limit
            for i in unused:
                d = np.hypot(found[i]["cx"] - tr["x"], found[i]["cy"] - tr["y"])
                if d < bestd:
                    best, bestd = i, d
            if best is None:
                continue                      # track lost; it simply ends
            b = found[best]
            unused.remove(best)
            tr.update(x=b["cx"], y=b["cy"], area=b["area"], peak=b["peak"],
                      luma=b["luma"], streak=tr["streak"] + 1)
            alive.append(tr)
        for i in unused:                      # anything left is a new spot
            b = found[i]
            self._next_id += 1
            alive.append({"id": self._next_id, "x": b["cx"], "y": b["cy"],
                          "area": b["area"], "peak": b["peak"], "luma": b["luma"],
                          "streak": 1})
        self._tracks = alive

        return [{"id": t["id"], "x": t["x"] / w, "y": t["y"] / h,
                 "area": t["area"], "peak": t["peak"], "luma": t["luma"],
                 "locked": t["streak"] >= self.lock_need}
                for t in self._tracks]

# --------------------------------------------------------------------- source
class PiCamera:
    DEFAULT_EXPOSURE_US = 2000        # global shutter behind a real filter
    DEFAULT_GAIN = 8.0                # analogue multiplier

    def __init__(self, width, height, exposure_us=2000, gain=8.0, fps=60):
        from picamera2 import Picamera2
        self.cam = Picamera2()
        # R8 asks libcamera for single-channel 8-bit, which is what a mono
        # sensor gives natively. Some stacks hand back 3 channels anyway, so
        # read() copes with both rather than assuming.
        cfg = self.cam.create_video_configuration(
            main={"size": (width, height), "format": "R8"},
            buffer_count=4,
        )
        self.cam.configure(cfg)
        frame_us = int(1_000_000 / fps)
        self.cam.set_controls({
            "AeEnable": False,          # the entire point of this camera
            "AwbEnable": False,
            "ExposureTime": exposure_us,
            "AnalogueGain": gain,
            "FrameDurationLimits": (frame_us, frame_us),
        })
        self.cam.start()
        time.sleep(0.5)

    def read(self):
        a = self.cam.capture_array("main")
        if a.ndim == 3:
            a = a[:, :, 0]
        return a

    def close(self):
        self.cam.stop()


def v4l2_manual(device, exposure_us, gain, verbose=True, auto=False):
    """Force manual exposure/gain/focus on a UVC camera via v4l2-ctl.

    This is the whole reason a modified webcam becomes usable on a Pi: the
    control that macOS refuses to hand over is available on Linux. Kernel
    versions disagree on the control names, so try both spellings and report
    what actually took - believe the readback, not the request.
    """
    import shutil, subprocess
    if sys.platform == "darwin" or not shutil.which("v4l2-ctl"):
        if verbose:
            print("v4l2   not available - exposure stays on auto "
                  "(expected on macOS; on a Pi: sudo apt install v4l-utils)")
        return False

    dev = f"/dev/video{device}"
    if auto:
        # Used only for the startup health check: a sensor on auto shows read
        # noise, which is what tells a live camera from a dead stream.
        for name in ("auto_exposure=3", "exposure_auto=3", "gain=64"):
            subprocess.run(["v4l2-ctl", "-d", dev, f"--set-ctrl={name}"],
                           capture_output=True, text=True)
        return True
    # exposure_time_absolute is in 100 us units, so 2000 us -> 20
    pairs = [
        ("auto_exposure", "1"), ("exposure_auto", "1"),          # 1 = manual
        ("exposure_time_absolute", str(max(1, exposure_us // 100))),
        ("exposure_absolute", str(max(1, exposure_us // 100))),
        ("exposure_dynamic_framerate", "0"),
        ("gain", str(int(gain))),
        ("focus_automatic_continuous", "0"), ("focus_auto", "0"),
        ("focus_absolute", "0"),
        ("white_balance_automatic", "0"), ("white_balance_temperature_auto", "0"),
    ]
    applied = []
    for name, value in pairs:
        r = subprocess.run(["v4l2-ctl", "-d", dev, f"--set-ctrl={name}={value}"],
                           capture_output=True, text=True)
        if r.returncode == 0:
            applied.append(name)
    if verbose:
        print(f"v4l2   applied: {', '.join(applied) if applied else 'nothing'}")
        r = subprocess.run(["v4l2-ctl", "-d", dev, "--list-ctrls"],
                           capture_output=True, text=True)
        for line in r.stdout.splitlines():
            if any(k in line for k in ("exposure", "gain", "focus")):
                print("      ", line.strip())
    return bool(applied)


class OpenCVCamera:
    """Any UVC webcam.

    On a Pi this is a first-class option, not just a stand-in: v4l2 gives real
    manual exposure, which is the single thing that makes IR tracking robust.
    A modified C910 here is a genuinely usable camera. On macOS the controls
    are refused and detection has to lean on the rolling background and
    adaptive threshold instead.
    """

    # Measured on a modified C910 behind VHS tape, LED at painting distance:
    #   2 ms  sig 16.9  thr 12.0  no detection
    #   6 ms  sig 55.4  thr 12.0  LOCKED      <- 4.6x margin, thr still on floor
    #  10 ms  sig 78.6  thr 17.2  LOCKED      <- signal up, margin flat
    #  20 ms  sig 123.6 thr 29.7  LOCKED      <- ambient now paying for it
    # Past 6 ms the adaptive threshold rises with the signal, so the margin stops
    # improving and only the room light grows. Short exposure is still what
    # rejects ambient - 6 ms is short - but 2 ms was dogma, not a measurement.
    DEFAULT_EXPOSURE_US = 6000
    DEFAULT_GAIN = 128                # 0-255 register, not a multiplier

    def __init__(self, width, height, fps=30, device=0,
                 exposure_us=6000, gain=128, **_):
        import cv2
        self.cv2 = cv2
        self.device = device
        for attempt in range(1, 4):
            self._open(width, height, fps)
            # Validate BEFORE going to a short exposure, while the sensor is on
            # auto and every frame should be full of read noise. A frame whose
            # pixels are all one value means the camera enumerated and streamed
            # but never actually started - the C910 does this on a cold plug
            # (the kernel log shows its first probe failing with -5), and the
            # only cure is to close it and open it again. Photo Booth shows the
            # same thing: pick the camera, pick another, pick it back.
            v4l2_manual(device, exposure_us, gain, verbose=False, auto=True)
            f = self._settle(20)
            if f is not None and int(f.max()) > int(f.min()):
                break
            print(f"camera returned a flat frame - reopening ({attempt}/3)")
            self.cap.release()
            time.sleep(0.6)
        else:
            print("camera never produced a live frame. Unplug it and plug it "
                  "back in; if that fails, check it in another app first.")

        cc = int(self.cap.get(cv2.CAP_PROP_FOURCC))
        fourcc = "".join(chr((cc >> 8 * i) & 0xFF) for i in range(4)) if cc else "?"
        print(f"camera actual frame {int(self.cap.get(cv2.CAP_PROP_FRAME_WIDTH))}"
              f"x{int(self.cap.get(cv2.CAP_PROP_FRAME_HEIGHT))} {fourcc} "
              f"@ {self.cap.get(cv2.CAP_PROP_FPS):.0f} fps")
        # Now drop to the short exposure the tracker actually wants. Re-applied
        # after opening because opening resets controls on some UVC drivers.
        v4l2_manual(device, exposure_us, gain)

    def _open(self, width, height, fps):
        cv2 = self.cv2
        backend = cv2.CAP_AVFOUNDATION if sys.platform == "darwin" else cv2.CAP_V4L2
        self.cap = cv2.VideoCapture(self.device, backend)
        if not self.cap.isOpened():
            sys.exit(f"could not open camera {self.device} "
                     "(on macOS, grant camera access to your terminal)")
        # Ask for MJPEG before asking for a size. V4L2 otherwise hands back
        # uncompressed YUYV, and 720p of that is ~18 MB/s - more than USB 2.0
        # will carry, so the camera silently drops to ~10 fps. Requesting the
        # format first is what makes a 30 fps mode available at all.
        if sys.platform != "darwin":
            self.cap.set(cv2.CAP_PROP_FOURCC, cv2.VideoWriter_fourcc(*"MJPG"))
        # Height first, then width: AVFoundation negotiates a whole mode, not
        # two independent numbers, and the order changes what you get.
        self.cap.set(cv2.CAP_PROP_FRAME_HEIGHT, height)
        self.cap.set(cv2.CAP_PROP_FRAME_WIDTH, width)
        self.cap.set(cv2.CAP_PROP_FPS, fps)

    def _settle(self, n):
        """Read n frames and return the last, giving auto exposure time to
        converge. Returns None if the camera stops handing over frames."""
        f = None
        for _ in range(n):
            ok, frame = self.cap.read()
            if not ok:
                return None
            f = frame
        if f is None:
            return None
        return self.cv2.cvtColor(f, self.cv2.COLOR_BGR2GRAY) if f.ndim == 3 else f

    def read(self):
        ok, f = self.cap.read()
        if not ok:
            return np.zeros((2, 2), np.uint8)
        return self.cv2.cvtColor(f, self.cv2.COLOR_BGR2GRAY) if f.ndim == 3 else f

    def close(self):
        self.cap.release()


class SyntheticCamera:
    """A moving dot on a noisy background, so the pipeline can be exercised and
    tested without the hardware."""

    def __init__(self, width, height, fps=60, **_):
        self.w, self.h = width, height
        self.t = 0
        self.rng = np.random.default_rng(0)
        self.led = True
        self.interval = 1.0 / fps if fps else 0
        self._next = time.time()

    def read(self):
        # Real cameras block at their frame rate; this one would spin as fast as
        # the CPU allows and flood the socket, so pace it deliberately.
        if self.interval:
            now = time.time()
            wait = self._next - now
            if wait > 0:
                time.sleep(wait)
            self._next = max(now, self._next) + self.interval
        self.t += 1
        img = (22 + self.rng.random((self.h, self.w)) * 14).astype(np.uint8)
        img[self.h // 3: self.h // 3 + self.h // 3, 40:40 + self.w // 4] = 110
        if self.led:
            cx = int(self.w * (0.5 + 0.3 * np.sin(self.t / 40)))
            cy = int(self.h * (0.5 + 0.2 * np.cos(self.t / 55)))
            yy, xx = np.ogrid[:self.h, :self.w]
            img[(yy - cy) ** 2 + (xx - cx) ** 2 <= 9] = 255
        return img

    def close(self):
        pass


# ----------------------------------------------------------------------- main
def parse_args():
    p = argparse.ArgumentParser(description=__doc__,
                                formatter_class=argparse.RawDescriptionHelpFormatter)
    p.add_argument("--source", choices=("picamera", "webcam", "synthetic"),
                   default="picamera",
                   help="webcam runs the whole chain on a laptop before the Pi arrives")
    p.add_argument("--device", type=int, default=0, help="webcam index")
    p.add_argument("--width", type=int, default=1280)
    p.add_argument("--height", type=int, default=800)
    p.add_argument("--fps", type=int, default=60)
    # gain means different things on the two backends - an analogue multiplier
    # on picamera2, a 0-255 sensor register on a UVC webcam - so there is no one
    # default that suits both. 8.0 is a reasonable picamera gain and very nearly
    # nothing on a webcam; leaving it shared meant the C910 ran at 8/255 for this
    # entire project, which is what capped its range.
    p.add_argument("--exposure", type=int, default=None,
                   help="microseconds. Short is the whole trick - 2000 is 2 ms")
    p.add_argument("--gain", type=float, default=None)
    p.add_argument("--k", type=float, default=10.0, help="threshold, in sigmas")
    p.add_argument("--floor", type=int, default=12)
    # An ABSOLUTE pixel threshold, so its meaning moves with gain and exposure.
    # It was 55, set once to kill false positives, and from then on it silently
    # set the maximum range: a blob had to be brighter than 55/255 no matter how
    # the camera was configured. Keep it just above sensor noise and let the
    # adaptive threshold and the persistence gating do the real filtering.
    p.add_argument("--min-luma", type=int, default=25)
    # Consecutive detections before a blob counts as a fix. This is PRESS
    # LATENCY, paid on every button press: at 30 fps each frame here is 33 ms,
    # and it was hard-coded at 3 - 100 ms - for the whole project. It exists to
    # reject single-frame false positives, which mattered when the signal sat
    # barely above threshold. With a 4.6x margin and a position stable to
    # +/-0.005, 2 is plenty and 1 is worth trying.
    p.add_argument("--max-blobs", type=int, default=2,
                   help="how many spots to track at once - one per can")
    p.add_argument("--min-area", type=int, default=24,
                   help="smallest blob in pixels. Rejects single-pixel noise, "
                        "which is what paints by itself at low --lock-need")
    p.add_argument("--lock-need", type=int, default=2,
                   help="frames before a fix is reported. Each one costs 33 ms "
                        "of latency between pressing the button and painting")
    p.add_argument("--port", type=int, default=WS_PORT)
    p.add_argument("--serve", type=int, default=0,
                   help="also serve the repo over HTTP on this port, e.g. 8000")
    p.add_argument("--send-rate", type=int, default=90,
                   help="max WebSocket messages per second. The browser paints "
                        "at 60; flooding it only adds buffer latency")
    p.add_argument("--stats", action="store_true",
                   help="print a live line for aiming and tuning")
    return p.parse_args()


# --------------------------------------------------------------- live preview
# At 2 ms the camera's frames look black to a human even when detection is
# working perfectly, so aiming the camera by eye is impossible without a
# stretched view - and an exhibition Pi has no screen of its own to put one on.
# Serve it over HTTP instead, and let whoever is aiming watch from a phone.
LATEST = {"gray": None, "blob": None, "stats": {}}
LATEST_LOCK = threading.Lock()
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

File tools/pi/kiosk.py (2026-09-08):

#!/usr/bin/env python3
"""Drive the wall app in a kiosk browser over the Chrome DevTools Protocol.

The exhibition Pi has no mouse or keyboard, so the page has to be operated
from outside it. Launch Chromium with --remote-debugging-port=9222 and this
evaluates JavaScript in the page from an SSH session.

    ./kiosk.py 'app.camMode'                  # read something
    ./kiosk.py --connect ws://localhost:8765  # go live on the Pi tracker
    ./kiosk.py --calibrate                    # start the 4-corner calibration
    ./kiosk.py --status                       # tracker state and last fix
"""
import asyncio, json, sys, urllib.request
import websockets

CDP = "http://localhost:9222"


async def evaluate(expr, timeout=30):
    targets = json.load(urllib.request.urlopen(f"{CDP}/json"))
    # Any page the kiosk is serving, not just the wall: the debug pointer page
    # has to be drivable too, and on a machine with no keyboard this is the only
    # way to press a key at all.
    page = next((t for t in targets
                 if t["type"] == "page" and "localhost:8000" in t["url"]), None) \
        or next((t for t in targets if t["type"] == "page"), None)
    if not page:
        sys.exit("no page target - is the kiosk browser running?")
    async with websockets.connect(page["webSocketDebuggerUrl"],
                                  max_size=None, open_timeout=10) as ws:
        await ws.send(json.dumps({
            "id": 1, "method": "Runtime.evaluate",
            "params": {"expression": expr, "awaitPromise": True,
                       "returnByValue": True}}))
        async with asyncio.timeout(timeout):
            while True:
                m = json.loads(await ws.recv())
                if m.get("id") != 1:
                    continue
                r = m.get("result", {})
                if "exceptionDetails" in r:
                    d = r["exceptionDetails"]
                    sys.exit("JS error: " + d.get(
                        "exception", {}).get("description", d.get("text", "?")))
                return r.get("result", {}).get("value")


# A screen wake lock, not a compositor setting: the app itself is what must
# keep the TV awake, and it is the only part that knows it is on show.
WAKELOCK = """
(async () => {
  try {
    window._wakeLock = await navigator.wakeLock.request('screen');
    document.addEventListener('visibilitychange', async () => {
      if (document.visibilityState === 'visible')
        try { window._wakeLock = await navigator.wakeLock.request('screen'); }
        catch (e) {}
    });
    return 'held';
  } catch (e) { return 'failed: ' + e.message; }
})()"""


def main():
    args = sys.argv[1:]
    # --timeout has to outlast the expression itself: a measurement that runs
    # for 30 s inside the page needs more than 30 s of patience outside it.
    timeout = 30
    if "--timeout" in args:
        i = args.index("--timeout")
        timeout = float(args[i + 1])
        del args[i:i + 2]
    if not args:
        sys.exit(__doc__)
    if args[0] == "--connect":
        url = args[1] if len(args) > 1 else "ws://localhost:8765"
        expr = f"""(async () => {{
          const wl = await {WAKELOCK};
          app.setCamMode('pi');
          app.piTracker.connect({url!r});
          await new Promise(r => setTimeout(r, 2500));
          return {{ wakeLock: wl, mode: app.camMode,
                   state: app.piTracker.state, stats: app.piTracker.stats }};
        }})()"""
    elif args[0] == "--calibrate":
        expr = ("(app.beginIRCalibration(), "
                "({calibrating: !!app._irCalibrating, mode: app.camMode, "
                "state: app.piTracker.state}))")
    elif args[0] == "--status":
        expr = """({
          mode: app.camMode, state: app.piTracker.state,
          calibrated: app.piTracker.calibrated,
          live: !!app.handTrackingOn,
          last: app.piTracker.last, stats: app.piTracker.stats })"""
    elif args[0] == "--latency":
        # Run this WHILE painting: it only samples when there is a fix, because
        # the tracker sends a timestamp only with a position.
        secs = float(args[1]) if len(args) > 1 else 20
        expr = f"""(async () => {{
          const t = app.piTracker, lat = []; let frames = 0, seen = null;
          const t0 = performance.now();
          const tick = () => {{ frames++;
            if (performance.now()-t0 < {secs*1000}) requestAnimationFrame(tick); }};
          requestAnimationFrame(tick);
          while (performance.now() - t0 < {secs*1000}) {{
            await new Promise(r => setTimeout(r, 50));
            if (t.latency != null && t.latency !== seen) {{ lat.push(t.latency); seen = t.latency; }}
          }}
          lat.sort((a,b)=>a-b);
          const q = f => lat.length ? lat[Math.min(lat.length-1, Math.floor(lat.length*f))] : null;
          return {{ samples: lat.length, min_ms: q(0), p50_ms: q(0.5),
                   p90_ms: q(0.9), max_ms: q(0.999),
                   rafFps: +(frames/((performance.now()-t0)/1000)).toFixed(1),
                   note: lat.length ? "" : "no fix seen - hold the button at the camera while this runs" }};
        }})()"""
        timeout = max(timeout, secs + 20)
    elif args[0] == "--wakelock":
        expr = WAKELOCK
    else:
        expr = args[0]
    print(json.dumps(asyncio.run(evaluate(expr, timeout)), indent=2))


if __name__ == "__main__":
    main()

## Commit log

2026-08-30 Add IR tracking: web app mode, python tuner, corrected can model
    Camera architecture changed. The original plan was to bounce IR off the
    wall and watch the reflection from the back of the room; measured, that is
    roughly 1000x too dim and is abandoned. The camera now sits at the wall
    looking back at the user, so the nozzle points straight at it and the
    camera sees the LEDs directly - verified to 3 m.
    test-wall.html: new "IR can" camera mode alongside the existing hand and
    colour-tracking modes. Pure-JS luma blob tracking (no opencv.js), rolling
    background that only updates where the frame is not lit so a held LED does
    not burn into the reference, adaptive mean+k*sigma threshold, persistence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
    [canv2.scad, project.3mf]
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2026-09-06 bottom_cap: move holder retention from the side rails to the front lips
    The CM battery holder's cable-management wings are eight discrete lugs
    reaching |x| 18.10 along the back half of its thickness. The old retention
    tabs bit inward from the side rails to |x| 16.95, so every one of those
    eight lugs had to force the rails apart by 1.15 mm during insertion - it
    jammed rather than clicked, and had to be clipped away to fit the holder.
    The holder's front half never exceeds 14.90 wide and the wings never reach
    the front, so the catch now sits on the front lips instead: 0.8 mm into the
    pocket, 3.6 mm wide, with a lead-in above. It engages the front face by
    2.55 mm and leaves the entire wing corr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
    [Full project September 6.3mf, bottom_cap.stl, canv2.scad]
2026-09-07 Add Pi tracker: OV9281 capture, blob detection, WebSocket output
    Runs headless on the Pi behind the TV. Fixed short exposure (2 ms default)
    with AE and AWB off - the control macOS never allowed, and the thing that
    does more for ambient rejection than any filter.
    Sends normalised IMAGE coordinates, not screen coordinates. The browser
    keeps the homography, because that is where the corner targets can be shown
    on the TV and test-wall.html already has solveHomography. The Pi stays a
    dumb blob detector.
    Detection is the same pipeline as tools/irtest.py and the browser tracker,
    including the two fixes found the hard way: the background updates only
    where the frame is not lit (otherwise a held LE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
    [Full project September 6.3mf]
2026-09-07 test-wall: add IR (Pi) mode driven by the tracker WebSocket
    Fourth camera mode alongside hand, colour can and local IR. PiTracker holds
    the last fix from tools/pi/tracker.py and applies the same homography the
    local tracker uses, so calibration, smoothing, stroke handling and the
    pen-up debounce are all shared rather than duplicated.
    PiTracker deliberately exposes the same shape as IRTracker - detect,
    processFrame, homography, W, H, last - so the calibration overlay and the
    paint loop no longer name a specific tracker. Added activeTracker() and
    routed the loop, the calibration and the readouts through it.
    The Pi already applies the persistence gate and only sends a position when
    locked, so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
2026-09-07 tracker: real manual exposure for UVC cameras on Linux
    The exposure limitation that has blocked this project was macOS's, not the
    camera's. On Linux v4l2 will set manual exposure, gain and focus on a UVC
    device, so the modified C910 plugged into a Pi becomes a genuinely usable
    camera rather than a stand-in - and the whole system can be built while the
    OV9281 is still in transit.
    v4l2_manual() tries both kernel spellings of each control (auto_exposure vs
    exposure_auto, exposure_time_absolute vs exposure_absolute) since versions
    disagree, prints what actually took, and re-applies after opening because
    some UVC drivers reset controls on open. It no-ops with an explanatory line
    on macOS or wher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
    [tracker.py]
2026-09-07 tracker: request MJPEG so the C910 runs at 30 fps, not 10
    V4L2 hands back uncompressed YUYV unless asked otherwise. 1280x720 YUYV
    is ~18 MB/s, more than USB 2.0 carries, so the camera silently settles at
    ~10 fps - measured on the Pi 5 with the modified C910. Asking for MJPEG
    before asking for a size gets the full rate back.
    Also pin exposure_dynamic_framerate off: it lets the driver stretch the
    exposure beyond the value just set, which would undo the short-exposure
    ambient rejection that makes IR tracking work in a lit room.
    Report the negotiated fourcc and rate at startup - believe the readback.
    [tracker.py]
2026-09-07 tools: add kiosk.py to drive the wall app on a headless Pi
    The exhibition Pi has no mouse or keyboard, so the page has to be operated
    from outside it. Chromium is launched with a remote debugging port and this
    evaluates JavaScript in the page over CDP from an SSH session: connect to
    the tracker, start the corner calibration, read tracker state.
    Also takes a screen wake lock, re-acquired on visibilitychange. The display
    blanking that killed the first session is the app's problem to solve, not
    the compositor's - the page is the only part that knows it is on show.
    [kiosk.py]
2026-09-07 tracker: serve a live camera preview for aiming
    At 2 ms exposure the frames look black to a human even when detection is
    working, so a covered lens and a correctly exposed IR frame are visually
    identical. The app's existing IR diagnostics can't help here: in Pi mode
    the browser only receives coordinates, never pixels.
    Serve /preview (page), /preview.mjpg (stream) and /snapshot.jpg from the
    tracker's HTTP server, contrast-stretched to full range with the detection
    crosshair and the live stats burned in. ?boost=0 shows true levels.
    [tracker.py]
2026-09-07 tracker: detect and recover from the C910's dead first open
    The camera enumerates, streams at a valid 30 fps, and hands back frames in
    which every pixel is the same value. It looks like a blocked lens and is
    not: the C910's first probe fails (dmesg shows -5) and the stream never
    really starts. Photo Booth shows the same thing - you have to select the
    camera, select another, and select it back.
    Validate at startup while still on auto exposure, where a live sensor
    always shows read noise, so a single-valued frame is unambiguous. On a flat
    frame, close and reopen, up to three times, then drop to the short exposure
    the tracker wants. Checking after the switch to 2 ms would not work: a dark
    room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
    [tracker.py]
2026-09-08 cap: nozzle for the 8 mm 3 W power emitter (850 nm, 120 deg)
    The 3 mm indicator LEDs were the binding constraint: measured on the Pi and
    on the Mac, lock only held within roughly +/-20 deg, in both cases, at 2 ms
    manual exposure and at 16 ms auto. Two sensitivity regimes that far apart
    giving the same usable cone says the limit is the beam, not the signal.
    So: one 120 deg emitter in place of the pair. From the drawing the body is
    8.0 round with a 6.0 dome, tabs 1.5 x 1.05 spanning 14.5 tip to tip.
    The nozzle is now bored in three steps from the face: 6.5 dome clearance,
    a shoulder at 1.6, then an 8.2 pocket running back into the wiring chamber.
    It seats on the body's TOP face, not its unde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
    [canv2.scad, cap_body.stl]
2026-09-08 cap: retain the LED on its tabs so the whole dome sits outside
    Bård's design, and it is better than the lip it replaces. The body now sits
    in an 8.2 bore that runs right out to the nozzle face, so it ends up flush
    and the entire 2.6 mm dome stands outside with nothing in front of it. No
    lip, no countersink, no vignetting: the full 120 degrees.
    Retention comes from the tabs instead. They span 14.5 and cannot pass an 8.2
    bore, so they bear on the ring behind it. That is why the spout is now sized
    by the tab span rather than the body, 13.2 -> 17.5, and why the tabs no
    longer need trimming.
    The lip version could not win: the mouth had to stay under the 8.0 body or
    the LED fell out the front,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
    [canv2.scad, cap_body.stl]
2026-09-08 cap: bore to the minimum body height, not the measured guess
    The bore depth was 3.65, taken from an uncertain measurement of the body.
    If the body is really 2.4 - which is what the drawing gives, 5.0 total less
    the 2.6 dome, and what Bård's read of the leg-to-body-top height suggests -
    then it sits 1.25 recessed and the bore clips the beam. That is exactly the
    failure the lip was removed to avoid, reintroduced by a soft number.
    The error is not symmetric, so the parameter should not be a best guess. Too
    short only stands the body a little proud: the tabs still bear, the dome is
    still completely clear, nothing is lost. Too long recesses the dome. So bore
    to the smallest body height that is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
    [canv2.scad, cap_body.stl]
2026-09-08 cap: thin the forward-facing wall to 0.8, and key it off the tab plane
    That wall is only a stop for the tabs - it never had to be as deep as the
    body - so it can be as thin as the printer will hold. 2.4 -> 0.8, two
    perimeters at a 0.4 nozzle.
    The thickness is set by where the tab slot ends, not by the bore length, and
    that was still keyed to pled_body_h: changing the ring parameter alone left
    the wall at 2.4 while reporting 0.8. Caught by the startup echo, which is
    what it is there for. pled_tab_y now derives from pled_ring.
    pled_body_h no longer touches the geometry at all and stays only to report
    how far the part ends up standing out, so an uncertain measurement cannot
    move the model aga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
    [canv2.scad, cap_body.stl]
2026-09-08 README: bring the project up to the new components
    Wiring is now one branch: a single 850 nm 120 degree emitter through 22 ohm,
    replacing the pair of 940 nm indicators through 100 ohm each. Polarity is
    printed on the part, so the long-leg/short-leg note is gone.
    Also updates what the file was getting wrong:
    - macOS exposure is no longer "the" blocker. The Pi sets the same controls
    and reads them back, so that section says so and records the numbers.
    - The beam angle is the blocker, and the decisive measurement is written
    down: the same +/-20 cone on a Mac at 16 ms auto and a Pi at 2 ms manual.
    - Reverses the purchasing advice. It recommended TSAL6100/6200 for
    intensity; those are +/-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
2026-09-08 tools: measure lock rate off the WebSocket, for the cone test
    The --stats line is a live display, not a record. It is overwritten in
    place, and on a C910 the MJPEG decoder interleaves warnings into the same
    stream, so sampling the log tail measures the sampling rather than the can -
    it reported 2/20 locked during a run that was in fact holding a solid fix.
    This subscribes to what the tracker broadcasts and counts it, with a rolling
    lock percentage. Built for the measurement that decides whether the 120 deg
    emitter did what it was bought to do: hold the can at a fixed distance,
    rotate, and read where the lock rate falls away.
    Treats a receive timeout as "no fix" rather than as a dead link,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
    [measure.py]
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2026-09-08 tools: kiosk.py --latency, measured while actually painting
    End-to-end latency can only be sampled when there is a fix, and the fix
    depends on someone holding the can at the camera - which is not something
    this end of the wire can arrange. Makes it a one-liner to run by hand.
    [kiosk.py]
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2026-09-08 test-wall: cut cursor smoothing latency, and make it tunable
    The EMA on the cursor costs latency in FRAMES, not seconds: ~5 frames to
    settle, so 150 ms at 33 fps and half a second back when the page was
    rendering at 10. alpha = 0.45 was chosen when the tracker was noisy and
    sitting barely above its threshold; it now delivers a position stable to
    +/-0.005 with 4.6x margin, so that filtering is no longer buying anything.
    0.45 -> 0.75, and exposed as app.canEmaAlpha so it can be tuned live against
    the actual feel rather than guessed at.
    Measured first: V4L2 buffering is NOT a contributor. Every read blocks ~33 ms
    waiting on the next frame, so the tracker is at the head of the queue, not
    drain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
2026-09-08 tracker: expose lock_need - it is press latency, and it was hard-coded
    A blob only counts as a fix after lock_need consecutive detections, and only
    locked blobs are sent. At 30 fps that is 33 ms per frame of pure delay
    between pressing the button and anything appearing, and it has been fixed at
    3 - 100 ms - since it was written, with no way to change it.
    It guards against single-frame false positives, which mattered when the
    signal sat barely over threshold. It now has 4.6x margin and a position
    stable to +/-0.005. Default 3 -> 2, exposed as --lock-need, and 1 is worth
    trying.
    [tracker.py]
2026-09-08 test-wall: repair the block the merge corrupted
    The merge spliced the tail of their onCanFrame into the middle of
    beginIRCalibration, and dropped toggleIRDiagnostics, startPreviewPump and
    endIRCalibration entirely. Syntactically valid, so node --check passed, and
    it failed only at runtime: "ReferenceError: r is not defined" the moment
    calibration was started.
    My verification was at fault too - I counted string occurrences rather than
    checking the methods were structurally intact, which is exactly the kind of
    damage a bad merge does. The block is restored from the pre-merge revision
    and the check now walks class and method boundaries.
2026-09-08 test-wall: drop the shadowing applyHomography the merge left behind
    Both sides defined applyHomography and the merge kept both. Unlike class,
    duplicate function declarations are legal - the last one silently wins - so
    their version was live: it takes an object-form H and returns an ARRAY, not
    {x, y}. processFrame then produced nx/ny of undefined, onCanFrame multiplied
    undefined by the canvas width, and the app painted at NaN. Calibration
    reported success, the cursor reported visible, a stroke was open, and
    nothing appeared.
    Both call sites want the {x, y} form, so theirs is removed.
    The verification that missed it checked duplicate CLASSES and class methods
    but not top-level functions - wh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
2026-09-08 tools: structural check for test-wall.html, to run after every merge
    One merge produced three silent breakages that a syntax check passes: a
    duplicate class (SyntaxError, nothing ran), a method block spliced into
    another method with three methods dropped (failed only on calibration), and
    a duplicate top-level function whose two versions returned different shapes
    (painted at NaN while reporting success).
    The last is the one worth automating: duplicate function declarations are
    legal and the last silently wins, so it is precisely the case nothing else
    complains about. Counting occurrences of a name does not catch any of these -
    a corrupted method still contains its own name - so this walks cl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
2026-09-08 test-wall: spray-to-open colour picker for the can
    The can has exactly one control, the trigger, so the only gestures it can
    make are where you point and how long you hold. Dwelling on the swatch bar
    for 900 ms opens a large-target menu; moving highlights a colour; releasing
    the trigger picks it, since letting go is the only "click" available.
    The bar's own swatches are 28 px, which the tracker cannot reliably hit from
    across a room, so the menu targets are 124 px and selection is by nearest
    centre rather than a hit test - forgiving of jitter, and there is always
    exactly one selection rather than dead space between targets.
    Painting is suppressed over the bar, and any stroke that wandered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
2026-09-08 tracker: reject single-pixel blobs - they were painting by themselves
    With --lock-need 1, which was set to cut press latency, one bad frame is a
    stroke. The wall started painting spontaneously, and the culprit was visible
    in an earlier log: a fix on a 2-pixel speck at 0.996,0.998 with peak 19.
    There was an upper area bound but no lower one. A real LED lights a patch -
    measured ~1000 px at painting distance, ~4300 close up - while these false
    positives were area 2. Filtering on size costs nothing: no latency like
    lock_need, no range like min_luma, because the gap is three orders of
    magnitude and the spot stays far above 24 px even at several metres.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
    [tracker.py]
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2026-09-08 test-wall: bigger pills, size shows its steps, one mode control, mouse parity
    Pills up ~50%: swatches 28 -> 42 px, pills 44 -> 66 tall. The size pill now
    shows all five steps with the current one ringed - a single dot gave no clue
    it was a control, nor which way the sizes ran.
    The top mode selector is gone. Two controls for one setting can disagree,
    and the bottom pill is the one the can can actually reach.
    The big menu is now fully mouse-operable: hover highlights, click picks,
    clicking the backdrop cancels. Highlighting is shared by the cursor and the
    mouse through one method rather than two paths that drift apart. Dropped the
    dblclick-to-open on the swatch bar - undiscoverable, and the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
2026-09-08 pi: boot straight into the wall, and into calibration
    Everything has been transient units typed by hand, so a reboot left a dead
    Pi. Two systemd USER services now bring it up: the graphical session has to
    exist first - the browser needs the compositor, and WAYLAND_DISPLAY only
    means anything inside that session - and the Pi already autologins, so they
    come up with it. No linger, no sudo.
    start-kiosk.sh waits for the compositor, sets 720p (measured: ~10 fps at
    1440p, ~15 at 1080p, 34+ at 720p, and wlr-randr does not persist), waits for
    the tracker's HTTP server, launches Chromium, then polls until the page
    answers over CDP before connecting and starting calibration.
    It always ends at the co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
2026-09-08 test-wall: panels inside the overflow menu no longer close it
    Moving the toolbar buttons into the overflow menu took their panels with
    them, and closeAllDropdowns closes .dropdown.open - which is now the menu the
    panel lives inside. Clicking Camera opened the panel and closed its parent in
    the same gesture, so it looked like nothing happened at all.
    The menu reopens when the button being toggled belongs to it, and clicks
    inside it no longer bubble to the document handler that closes everything.
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2026-09-08 test-wall: say when the tracker connects, and reconnect if it drops
    "Connecting to ws://…" was set on click and never replaced. onopen only set
    an internal state, so a successful connection looked exactly like a hung
    one - verified from the Mac that the socket was fine while the panel still
    claimed it was connecting.
    State changes now drive the panel text, including telling you to calibrate,
    which is the actual next step and was not signposted anywhere.
    Also reconnects. The Pi restarts its tracker on failure so the socket comes
    back by itself, but the page gave up on the first drop - and noticing a dead
    wall on a machine with no keyboard means noticing from across the room.
    Co-Authored-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
2026-09-09 wall.html: drips back, by growing instead of moving
    The old drips redrew every live drip onto a cleared full-screen overlay each
    frame - the exact pattern this rebuild exists to avoid. But a drip does not
    need to move: it grows. Extending it a few pixels downward per frame is
    purely additive, never needs erasing, and is what gravity actually does.
    Measured: 8 active drips cost 0.007 ms per frame, and when there are none
    the cost is one array-length check. Per-theme character is preserved - ink
    runs slow and dark with multiply blend, spray runs longer and lighter, and
    Space has none, because paint does not run in zero gravity.
    Calibration is now a faithful port of the old one rather than my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
2026-09-09 wall.html: secret menu on the frog, and Friedolin mode
    Clicking the frog - or resting a can on it, it is a dwell target like any
    pill - opens Calibrate / Reload / Friedolin. Operator things, reachable
    without a keyboard, and not somewhere a visitor falls into by accident.
    Friedolin paints the frog silhouette, the same artwork the old stencil used.
    It is tinted once per colour into an offscreen canvas and blitted like every
    other stamp: an <img> cannot be recoloured when drawn directly, and doing it
    per stamp is exactly the per-draw cost this build exists to avoid. It is
    deliberately NOT in THEME_ORDER, so the mode pill does not show it.
    Also adds theme.minStep. along() always places at lea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
2026-09-09 wall.html: Friedolin is a stencil mask, not a brush
    I built it as a brush that stamped little frogs. It is a MASK: a large
    silhouette placed on the wall, inside which paint shows and outside which it
    does not. Bård corrected it against the original.
    Built as a Path2D from the artwork's own path data rather than a raster
    mask, so the edge is exact at any size and applying it is one clip call
    instead of compositing a full-screen mask per stroke. The clip is set under
    the placement transform and the transform then reset - a clip lives in
    device space, so drawing afterwards happens in plain canvas coordinates with
    the mask still in force.
    Everything that marks the canvas goes through masked()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
2026-09-09 wall.html: spray hiss and the ink mirror, both from the original
    Sound was never ported - the original has it and this did not. Filtered white
    noise, one looping buffer through a highpass into a bandpass, exactly as
    before. It runs on the audio thread, so the main thread only nudges three
    parameters: level from speed, pan from x, brightness from height and speed.
    Built lazily on the first stroke because browsers refuse an AudioContext
    before interaction, and the kiosk now passes
    --autoplay-policy=no-user-gesture-required - a can is not a user gesture, so
    without it the context would sit suspended forever on the exhibition machine.
    Ink Wall mirrors about the vertical centre again, drips incl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
2026-09-09 wall.html: Space gets its own layer; boot into wall.html; bigger frog
    The Pi now boots into wall.html rather than test-wall.html. WALL_URL still
    overrides it, so the old wall is one env var away.
    Space was flat because its sky had been reduced to stars painted once. It now
    gets a layer of its own - a starfield, a brighter twinkling layer, and three
    drifting nebulae - built on entry and torn down on exit. The motion is CSS
    transforms and opacity, so it is compositor work: no per-frame JavaScript and
    no canvas re-upload, which is what made an animated sky unaffordable before.
    Strokes also string lit planets, some ringed, along the trail.
    Isolation measured, not asserted: with Space active th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
2026-09-09 wall.html: ink drips keep their colour instead of going black
    The colour was never wrong - the drip stored #232c4d and rendered rgb(2,3,9).
    Ink drips blended with multiply, and a drip GROWS by overlapping stamps: it
    advances 1.6 px a frame with a ~30 px stamp, so every pixel is multiplied
    about nineteen times. Multiply compounds, so any colour converges to black,
    and the darker the palette the faster it gets there.
    source-over instead. Measured after the change: an indigo drip renders
    rgb(35,44,77) at both its head and mid-length - exactly the swatch.
    The stroke keeps its inky character; it never used multiply, only the drips
    did.
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
